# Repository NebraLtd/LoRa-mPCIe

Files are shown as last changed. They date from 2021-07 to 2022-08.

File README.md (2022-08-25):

# LoRa-mPCIe
Open source mPCIe LoRa® concentrators from Nebra

## Branches

This repo contains a number of branches with different versions of the LoRa mPCIe hardware as set out below.

### Main

The [main branch of this repo](https://github.com/NebraLtd/LoRa-mPCIe) contains the initial design of the SX1302/3 concentrator but it is based on the original version of the Semtech reference design. It is therefore outdated and is here just for reference purposes. **This hardware has not been verified with prototypes. We do not recommend you use this design.**

### v1.1

The [v1.1 branch of this repo](https://github.com/NebraLtd/LoRa-mPCIe/tree/v1.1) is the latest version of the SX1302/3 based LoRa concentrator design, based on the v3 Semtech Corecell reference design.

There are multiple variants (USB/SPI versions, GNSS/no-GNSS versions and different frequency options). Visit the [v1.1 VARIANTS file](https://github.com/NebraLtd/LoRa-mPCIe/blob/v1.1/VARIANTS.md) for more information on the different hardware versions and how to produce them.

### v1.2
The development can be followed on the v1.2 branch but keeping the branch unmerged to master would create issues as branches generally accepted as unstable. Also the design will be ended with v1.2 from various reasons (Branding issues with Semtech, semantic versioning does not work in hardware design as in software development)

The variant files also can be observed in the Output's folder under their respective folders.

Note: Successor of this design will appear soon in another repo.

### 470/433

In the future, we will have our 470 MHz and 433 MHz designs available as well. As the design differs considerably from the 868/915 versions it may be in a separate branch.

## Open Source Hardware Certification

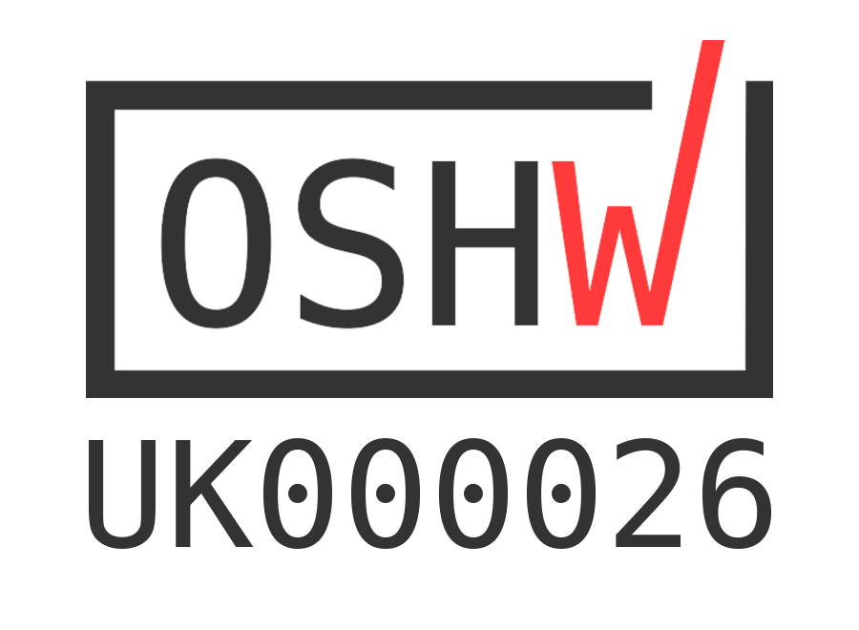
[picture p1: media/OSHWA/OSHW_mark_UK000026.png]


We are proud to announce that the Nebra LoRa mPCIe Concentrator project is certified as Open Source Hardware by the Open Source Hardware Association ([OSHWA](https://www.oshwa.org/)). The registration number for this project is [UK000026](https://certification.oshwa.org/uk000026.html).

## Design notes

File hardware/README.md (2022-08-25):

# LoRa Gateway mini-PCIe Module (SX1302/3) KiCad Open Source Design

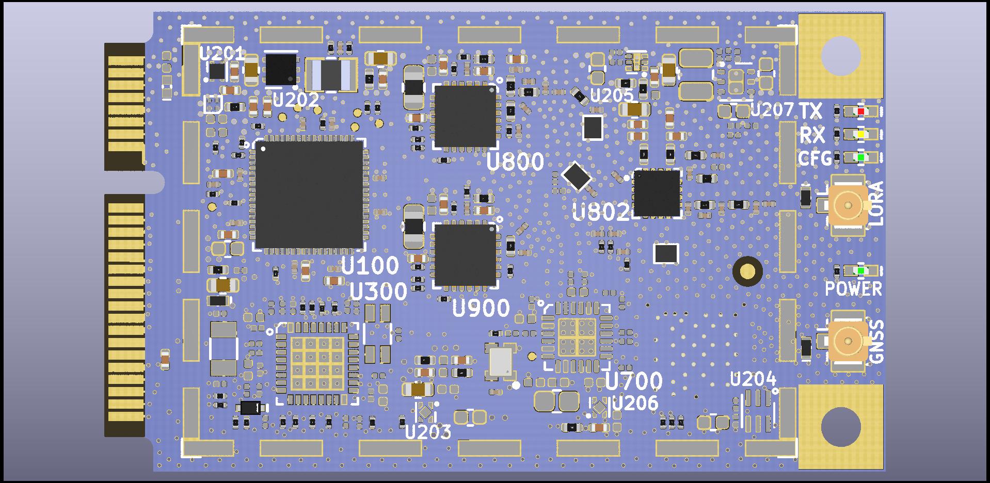
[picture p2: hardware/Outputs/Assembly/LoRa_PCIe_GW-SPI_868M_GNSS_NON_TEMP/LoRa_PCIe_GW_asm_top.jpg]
LoRa_PCIe_GW_asm_top


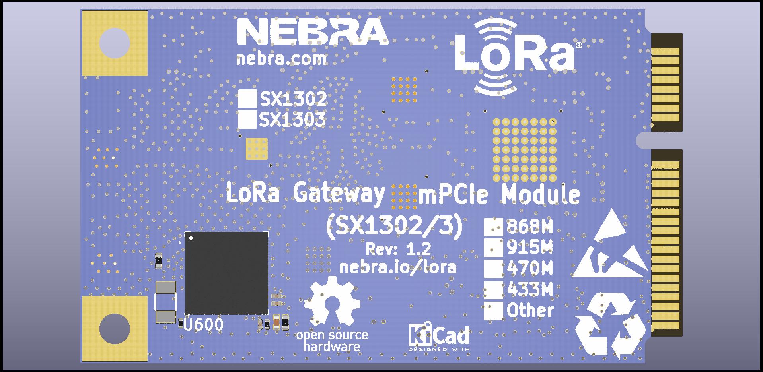
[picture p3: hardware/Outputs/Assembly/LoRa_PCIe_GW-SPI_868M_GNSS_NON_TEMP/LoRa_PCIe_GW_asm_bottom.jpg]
LoRa_PCIe_GW_asm_bottom


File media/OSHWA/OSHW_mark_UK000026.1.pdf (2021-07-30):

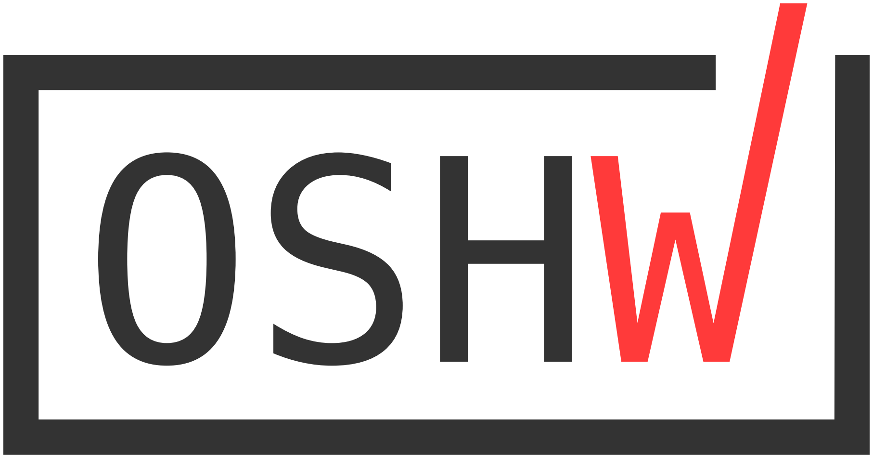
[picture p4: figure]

UK000026

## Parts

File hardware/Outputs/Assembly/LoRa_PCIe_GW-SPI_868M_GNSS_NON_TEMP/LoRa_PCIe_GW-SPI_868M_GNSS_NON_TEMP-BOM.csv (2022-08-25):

Reference | Quantity | Value | Footprint | Datasheet | Description | Manufacturer | Part Number | Price[1k] | Supplier Link | Label | Alternatives | Alternative1
A2 A1 | 2 | U.FL | LoRa_PCIe_GW:U.FL-R-SMT_Hirose |  | U.FL (UMCC) Connector Receptacle, Male Pin 50Ohm Surface Mount Solder | Hirose | U.FL-R-SMT-1(80) | 0.65 | https://www.digikey.com/en/products/detail/hirose-electric-co-ltd/U-FL-R-SMT-1-80/3978495 | GPS
C101 C111 C112 C104 C202 C201 C200 C226 C816 C916 | 10 | 1uF | LoRa_PCIe_GW:ccer_402_smd_small |  | 1µF ±20% 10V Ceramic Capacitor X5R 0402 (1005 Metric) | Murata | GRM153R61A105ME95D | 0.038 | https://www.digikey.com/en/products/detail/murata-electronics/GRM153R61A105ME95D/4904820
C108 C107 C105 C102 C110 C109 C103 C106 C100 C600 C602 C838 | 12 | 100nF | LoRa_PCIe_GW:ccer_201_smd_small |  | 0.1µF ±10% 16V Ceramic Capacitor X7S 0201 (0603 Metric) | Murata | GRM033C71C104KE14D | 0.01 | https://www.digikey.com/en/products/detail/murata-electronics/GRM033C71C104KE14D/5027472
C203 | 1 | 10uF | LoRa_PCIe_GW:ccer_603_smd_small |  | 10µF ±10% 16V Ceramic Capacitor X5R 0603 (1608 Metric) | Murata | GRM188R61C106KAAL | 0.1 | https://www.digikey.com/en/products/detail/murata-electronics/GRM188R61C106KAALJ/4905339
C204 C822 | 2 | 4.7uF | LoRa_PCIe_GW:ccer_603_smd_small |  | 4.7µF ±10% 16V Ceramic Capacitor X5R 0603 (1608 Metric) | Murata | GRM188R61C475KAAJD | 0.089 | https://www.digikey.com/en/products/detail/murata-electronics/GRM188R61C475KAAJD/5027566
C224 | 1 | 4.7uF | LoRa_PCIe_GW:ccer_402_smd_small |  | 4.7µF ±20% 6.3V Ceramic Capacitor X5R 0402 (1005 Metric) | Murata | GRM155R60J475ME47D | 0.089 | https://www.digikey.com/en/products/detail/murata-electronics/GRM155R60J475ME47D/3694656
C231 | 1 | 22pF | LoRa_PCIe_GW:ccer_201_smd_small |  | 22PF ±1% 50V Ceramic Capacitor C0G, NP0 0201 (0603 Metric) | Murata | GRM0335C1H220FA01D | 0.01 | https://www.digikey.com/en/products/detail/murata-electronics/GRM0335C1H220FA01D/11618542
C308 C206 C215 | 3 | 47uF | LoRa_PCIe_GW:ccer_603_smd_small |  | Multilayer ceramic capacitors X5R ±20%, 6.3V | Murata | GRM188R60J476ME15D | 0.1 | https://www.digikey.com/en/products/detail/murata-electronics/GRM188R61C106KAALJ/4905339
C312 C221 C220 C208 C210 C216 C818 C918 | 8 | 100nF | LoRa_PCIe_GW:ccer_402_smd_small |  | Multilayer ceramic capacitors X7R ±10%, 16V | Murata | GMD155R71C104KA11 | 0.01 | https://www.digikey.com/en/products/detail/murata-electronics/GMD155R71C104KA11D/10696609
C601 C802 | 2 | 47pF | LoRa_PCIe_GW:ccer_201_smd_small |  | 47pF ±5% 50V Ceramic Capacitor C0G, NP0 0201 (0603 Metric) | Murata | GRM0335C1H470JA01D | 0.0036 | https://www.digikey.com/en/products/detail/murata-electronics/GRM0335C1H470JA01D/2542245
C801 | 1 | 47nF | LoRa_PCIe_GW:ccer_402_smd_small |  | 0.047µF ±10% 16V Ceramic Capacitor X7R 0402 (1005 Metric) | Murata | GRM155R71C473KA01J | 0.012 | https://www.digikey.com/en/products/detail/murata-electronics/GRM155R71C473KA01J/2610901
C804 C832 C831 | 3 | 3.3pF | LoRa_PCIe_GW:ccer_201_smd_small |  | 3.3pF ±0.05pF 50V Ceramic Capacitor C0G, NP0 0201 (0603 Metric) | Murata | GJM0335C1H3R3WB01D | 0.026 | https://www.digikey.com/en/products/detail/murata-electronics/GJM0335C1H3R3WB01D/13401747
C805 | 1 | 5.6pF | LoRa_PCIe_GW:ccer_201_smd_small |  | 5.6pF ±0.05pF 50V Ceramic Capacitor C0G, NP0 0201 (0603 Metric) | Murata | GRM0335C1H5R6WA01D | 0.005 | https://www.digikey.com/en/products/detail/murata-electronics/GRM0335C1H5R6WA01D/11618868
C806 | 1 | 39pF | LoRa_PCIe_GW:ccer_201_smd_small |  | 39pF ±1% 50V Ceramic Capacitor C0G, NP0 0201 (0603 Metric) | Murata | GRM0335C1H390FA01D | 0.0057 | https://www.digikey.com/en/products/detail/murata-electronics/GRM0335C1H390FA01D/11618461
C807 | 1 | 2.2pF | LoRa_PCIe_GW:ccer_201_smd_small |  | 2.2pF ±0.05pF 50V Ceramic Capacitor C0G, NP0 0201 (0603 Metric) | Murata | GJM0335C1H2R2WB01D | 0.026 | https://www.digikey.com/en/products/detail/murata-electronics/GJM0335C1H2R2WB01D/11618467
C808 C908 C828 | 3 | 10pF | LoRa_PCIe_GW:ccer_201_smd_small |  | 10pF ±1% 50V Ceramic Capacitor C0G, NP0 0201 (0603 Metric) | Murata | GRM0335C1H100FA01 | 0.005 | https://www.digikey.com/en/products/detail/murata-electronics/GRM0335C1H100FA01J/4358681
C811 C812 C911 C912 | 4 | 3.6pF | LoRa_PCIe_GW:ccer_201_smd_small |  | 3.6pF ±0.05pF 25V Ceramic Capacitor C0G, NP0 0201 (0603 Metric) | Murata | GJM0335C1E3R6WB01J | 0.022 | https://www.digikey.com/en/products/detail/murata-electronics/gjm0335c1e3r6wb01j/2592609
C817 C917 | 2 | 470nF | LoRa_PCIe_GW:ccer_402_smd_small |  | 0.47µF ±10% 10V Ceramic Capacitor X5R 0402 (1005 Metric) | Murata | GRM155R61A474KE15D | 0.024 | https://www.digikey.com/en/products/detail/murata-electronics/GRM155R61A474KE15D/702528
C823 | 1 | 10nF | LoRa_PCIe_GW:ccer_402_smd_small |  | 10000pF ±10% 10V Ceramic Capacitor X5R 0402 (1005 Metric) | Murata | GRM155R61A103KA01D | 0.007 | https://www.digikey.com/en/products/detail/murata-electronics/GRM155R61A103KA01D/2610840
C824 | 1 | 1nF | LoRa_PCIe_GW:ccer_402_smd_small |  | 1000pF ±10% 16V Ceramic Capacitor X7R 0402 (1005 Metric) | Murata | GRM155R71C102KA01D | 0.007 | https://www.digikey.com/en/products/detail/murata-electronics/GRM155R71C102KA01D/2610889
C826 C825 | 2 | 100pF | LoRa_PCIe_GW:ccer_402_smd_small |  | 100pF ±1% 50V Ceramic Capacitor C0G, NP0 0402 (1005 Metric) | Murata | GRM1555C1H101FA01D | 0.016 | https://www.digikey.com/en/products/detail/murata-electronics/GRM1555C1H101FA01D/3693919
C829 | 1 | 1.3pF | LoRa_PCIe_GW:ccer_201_smd_small |  | 1.3pF ±0.05pF 50V Ceramic Capacitor C0G, NP0 0201 (0603 Metric) | Murata | GJM0335C1H1R3WB01 | 0.02 | https://www.digikey.com/en/products/detail/murata-electronics/GJM0335C1H1R3WB01D/11618853
C830 | 1 | 1.5pF | LoRa_PCIe_GW:ccer_201_smd_small |  | 1.5pF ±0.05pF 50V Ceramic Capacitor C0G, NP0 0201 (0603 Metric) | Murata | GJM0335C1H1R5WB01 | 0.026 | https://www.digikey.com/en/products/detail/murata-electronics/GJM0335C1H1R5WB01D/11618773
C833 | 1 | 2.7pF | LoRa_PCIe_GW:ccer_201_smd_small |  | 2.7 pF ±0.1pF 50V Ceramic Capacitor C0G, NP0 0201 (0603 Metric) | Murata | GJM0335C1H2R7BB01D | 0.008 | https://www.digikey.com/en/products/detail/murata-electronics/GJM0335C1H2R7BB01D/9758987
C834 C819 C815 C820 C821 C809 | 6 | 56pF | LoRa_PCIe_GW:ccer_201_smd_small |  | 56pF ±1% 50V Ceramic Capacitor C0G, NP0 0201 (0603 Metric) | Murata | GRM0335C1H560FA01D | 0.0057 | https://www.digikey.com/en/products/detail/murata-electronics/GRM0335C1H560FA01D/11618638
D101 | 1 | BAT54 | LoRa_PCIe_GW:SOD523 |  | Schottky 200mA (DC) Surface Mount SOD-523 | ON Semiconductor | BAT54XV2T1G | 0.046 | https://www.digikey.com/en/products/detail/on-semiconductor/BAT54XV2T1G/918321
D302 | 1 | 20V | LoRa_PCIe_GW:SLP1006P2T |  | 20V Clamp 4A (8/20µs) Ipp Tvs Diode Surface Mount SLP1006P2T | Semtech | RCLAMP0531T.TCT | 0.39 | https://www.digikey.com/en/products/detail/semtech-corporation/RCLAMP0531T-TCT/2236834
D600 D801 | 2 | ~ | LoRa_PCIe_GW:SLP1006P2T |  | TVS DIODE 4V 1005 | Murata | LXES15AAA1-153 | 0.046 | https://www.digikey.com/en/products/detail/murata-electronics/LXES15AAA1-153/5843762
FB302 FB208 FB207 FB212 FB203 FB211 FB801 | 7 | Ferrite beads | LoRa_PCIe_GW:rlc_402_smd_small |  | 10 Ohms @ 100MHz 1 Power Line Ferrite Bead 0402 (1005 Metric) 1A 25mOhm | Murata | BLM15PG100SN1D | 0.027 | https://www.digikey.com/en/products/detail/murata-electronics/BLM15PG100SN1D/2587980
L200 | 1 | 2.2uH | LoRa_PCIe_GW:LQM2HPN2R2MJ0L |  | 2.2µH Shielded Multilayer Inductor 1A 150mOhm Max 1008 (2520 Metric) | Murata | LQM2HPN2R2MJ0L | 0.14 | https://www.digikey.com/en/products/detail/murata-electronics/LQM2HPN2R2MJ0L/2594611
L601 L801 | 2 | 47nH | LoRa_PCIe_GW:rlc_402_smd_small |  | 47nH Unshielded Wirewound Inductor 210mA 1.08Ohm Max 0402 (1005 Metric) | Murata | LQW15AN47NJ00D | 0.063 | https://www.digikey.com/en/products/detail/murata-electronics/LQW15AN47NJ00D/584363
L803 | 1 | 2.5nH | LoRa_PCIe_GW:rlc_402_smd_small |  | 2.5nH Unshielded Wirewound Inductor 850mA 50mOhm Max 0402 (1005 Metric) | Murata | LQW15AN2N5C00D | 0.066 | https://www.digikey.com/en/products/detail/murata-electronics/LQW15AN2N5C00D/2594887
L804 | 1 | 4.7nH | LoRa_PCIe_GW:rlc_402_smd_small |  | 4.7nH Unshielded Wirewound Inductor 750mA 70mOhm Max 0402 (1005 Metric) | Murata | LQW15AN4N7C00D | 0.066 | https://www.digikey.com/en/products/detail/murata-electronics/LQW15AN4N7C00D/584348
L806 L906 | 2 | 12nH | LoRa_PCIe_GW:rlc_402_smd_small |  | 12nH Unshielded Wirewound Inductor 500mA 140mOhm Max 0402 (1005 Metric) | Murata | LQW15AN12NH00D | 0.066 | https://www.digikey.com/en/products/detail/murata-electronics/LQW15AN12NH00D/2594852
L807 L907 | 2 | 15uH | LoRa_PCIe_GW:rlc_805_smd_small |  | 15µH Shielded Multilayer Inductor 250mA 950mOhm 0805 (2012 Metric) | TDK | MLZ2012M150WTD25 | 0.068 | https://www.digikey.com/en/products/detail/tdk-corporation/MLZ2012M150WTD25/4743191
L809 | 1 | 6.8nH | LoRa_PCIe_GW:rlc_402_smd_small |  | 6.8nH Unshielded Wirewound Inductor 1.45A 68mOhm Max 0402 (1005 Metric) | Murata | LQW15AN6N8G80D | 0.1 | https://www.digikey.com/en/products/detail/murata-electronics/LQW15AN6N8G80D/4905972
L810 | 1 | 3.0nH | LoRa_PCIe_GW:rlc_402_smd_small |  | 3nH Unshielded Wirewound Inductor 1.35A 63mOhm Max 0402 (1005 Metric) | Murata | LQW15AN3N0C80D | 0.09 | https://www.digikey.com/en/products/detail/murata-electronics/LQW15AN3N0C80D/4905927
L811 | 1 | 7.5nH | LoRa_PCIe_GW:rlc_402_smd_small |  | 7.5nH Unshielded Wirewound Inductor 570mA 130mOhm Max 0402 (1005 Metric) | Murata | LQW15AN7N5J00D | 0.063 | https://www.digikey.com/en/products/detail/murata-electronics/LQW15AN7N5J00D/584352
L812 | 1 | 1.2nH | LoRa_PCIe_GW:rlc_402_smd_small |  | 1.2nH Unshielded Thick Film Inductor 390mA 100mOhm Max 0402 (1005 Metric) | Murata | LQP15MN1N2B02 | 0.07 | https://www.digikey.com/en/products/detail/murata-electronics/LQP15MN1N2B02D/584334
L813 L814 | 2 | 5.6nH | LoRa_PCIe_GW:rlc_402_smd_small |  | 5.6nH Unshielded Wirewound Inductor 800mA 51mOhm Max 0402 (1005 Metric) | Murata | LQW15AN5N6D10D | 0.072 | https://www.digikey.com/en/products/detail/murata-electronics/LQW15AN5N6D10D/2594939
LED1 | 1 | RED | LoRa_PCIe_GW:CD1005-0402-RED |  | Red 630nm LED Indication - Discrete 1.95V 0402 (1005 Metric) | Kingbright | APHHS1005SURCK | 0.12 | https://www.digikey.com/en/products/detail/kingbright/APHHS1005SURCK/1747502 | TX_ON
LED2 LED4 | 2 | GREEN | LoRa_PCIe_GW:CD1005-0402 |  | Green 570nm LED Indication - Discrete 1.9V 0402 (1005 Metric) | Kingbright | APHHS1005LCGCK | 0.11 | https://www.digikey.com/en/products/detail/kingbright/APHHS1005LCGCK/7318974 | CONFIG_OK
LED3 | 1 | YELLOW | LoRa_PCIe_GW:CD1005-0402-YELLOW |  | Yellow 590nm LED Indication - Discrete 1.85V 0402 (1005 Metric) | Kingbright | APHHS1005LSYCK/J3-PF | 0.16 | https://www.digikey.com/en/products/detail/kingbright/APHHS1005LSYCK-J3-PF/7318978 | RX_ON
R102 R301 R308 R309 R302 R317 R316 R318 R319 R332 R334 R331 R333 R326 | 14 | 100R | LoRa_PCIe_GW:rlc_201_smd_small |  | 100 Ohms ±1% 0.05W, 1/20W Chip Resistor 0201 (0603 Metric) Thick Film | Vishay Dale | CRCW0201100R | 0.037 | https://www.digikey.com/en/products/detail/vishay-dale/CRCW0201100RFKED/1967973
R103 R101 R107 R201 | 4 | 47k | LoRa_PCIe_GW:rlc_201_smd_small |  | 47 kOhms ±5% 0.05W, 1/20W Chip Resistor 0201 Thick Film | Vishay Dale | CRCW020147K0 | 0.039 | https://www.digikey.com/en/products/detail/vishay-dale/CRCW020147K0FKED/1968131
R104 R105 | 2 | 680R | LoRa_PCIe_GW:rlc_201_smd_small |  | 680 Ohms ±1% 0.05W, 1/20W Chip Resistor 0201 (0603 Metric) Thick Film | Vishay Dale | CRCW0201680R | 0.011 | https://www.digikey.com/en/products/detail/vishay-dale/CRCW0201680RFNED/1199791
R106 | 1 | 820R | LoRa_PCIe_GW:rlc_201_smd_small |  | 820 Ohms ±5% 0.05W, 1/20W Chip Resistor 0201 (0603 Metric) Thick Film | Vishay Dale | CRCW0201820R | 0.012 | https://www.digikey.com/en/products/detail/vishay-dale/CRCW0201820RJNED/1178449
R108 R600 | 2 | 10R | LoRa_PCIe_GW:rlc_201_smd_small |  | 10 Ohms ±5% 0.05W, 1/20W Chip Resistor 0201 Thick Film | Vishay Dale | CRCW020110R0JNED | 0.0052 | https://www.digikey.com/en/products/detail/vishay-dale/CRCW020147K0FKED/1968131
R113 R122 R114 R124 R110 R115 R112 R123 R121 R120 R109 R125 R111 R602 R200 R815 | 16 | 0R | LoRa_PCIe_GW:rlc_201_smd_small |  | 0 Ohms Jumper 0.05W, 1/20W Chip Resistor 0201 (0603 Metric) Thick Film | Vishay Dale | CRCW02010000Z0ED | 0.006 | https://www.digikey.com/en/products/detail/vishay-dale/CRCW02010000Z0ED/1178434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
R116 R117 R601 R206 R203 | 5 | 4.7k | LoRa_PCIe_GW:rlc_201_smd_small |  | 4.7 kOhms ±1% 0.05W, 1/20W Chip Resistor 0201 (0603 Metric) Thick Film | Vishay Dale | CRCW02014K70FNED | 0.011 | https://www.digikey.com/en/products/detail/vishay-dale/CRCW02014K70FNED/1199881
R221 R222 R813 R913 | 4 | 0R | LoRa_PCIe_GW:rlc_402_smd_small |  | CRCW04020000ZSTD | Vishay Dale | CRCW04020000ZSTD | 0.014 | https://www.digikey.com/en/products/detail/vishay-dale/CRCW04020000ZSTD/1226552
R231 R232 | 2 | 182K | LoRa_PCIe_GW:rlc_201_smd_small |  | 182K OHM 1% 1/20W, Thick Film | Vishay Dale | CRCW0201182KFKED | 0.039 | https://www.digikey.com/en/products/detail/vishay-dale/CRCW0201182KFKED/1968150
R330 R208 R805 R809 R807 | 5 | 1k | LoRa_PCIe_GW:rlc_201_smd_small |  | 1k Ohm ±5% 0.05W, 1/20W Chip Resistor 0201 (0603 Metric) - Thick Film | Vishay Dale | CRCW02011K00JNED | 0.073 | https://www.digikey.com/en/products/detail/vishay-dale/CRCW02011K00JNED/1178450
R801 R901 | 2 | 220R | LoRa_PCIe_GW:rlc_201_smd_small |  | 220 Ohms ±5% 0.05W, 1/20W Chip Resistor 0201 (0603 Metric) Thick Film | Vishay Dale | CRCW0201220RJNED | 0.007 | https://www.digikey.com/en/products/detail/vishay-dale/CRCW0201220RJNED/1178444
RF1 | 1 | Shield Frame | LoRa_PCIe_GW:SMS-458F_Shield | https://leadertechinc.com/wp-content/uploads/2016/03/SMS-458-REV-A.pdf | RF Shield Frame 1.070 (27.18mm) X 1.540" (39.12mm) Surface Mount" | Leader Tech | SMS-458F | 1.82 | https://www.digikey.com/en/products/detail/leader-tech-inc/SMS-458F/7203557
RF2 | 1 | Shield Cover | LoRa_PCIe_GW:SMS-458C_Shield_cover | https://leadertechinc.com/wp-content/uploads/2016/03/SMS-458-REV-A.pdf | RF Shield Cover 1.094 (27.79mm) X 1.564" (39.73mm) Non-Vented Surface Mount" | Leader Tech | SMS-458C | 0.32 | https://www.digikey.com/en/products/detail/leader-tech-inc/SMS-458C/7203485
U100 | 1 | SX1303 | LoRa_PCIe_GW:vqfn68_7x7mm | https://semtech.my.salesforce.com/sfc/p/ | Digital Baseband Chip for LoRaWAN network gateways | Semtech Corporation | SX1303IMLTRT | 20 | https://www.digikey.com/en/products/detail/semtech-corporation/SX1303IMLTRT/13419419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
U201 | 1 | 3V3 | LoRa_PCIe_GW:UDFN4_1x1mm |  | Linear Voltage Regulator IC Positive Fixed 1 Output 300mA 4-UDFN (1.0x1.0) | ON Semiconductor | NCP114AMX330TCG | 0.079 | https://www.digikey.com/en/products/detail/on-semiconductor/NCP114AMX330TBG/6166731 |  | NCP4586DMU33TCG
U202 | 1 | TPS62260DRV | LoRa_PCIe_GW:DRV0006A_V |  | Buck Switching Regulator IC Positive Adjustable 0.6V 1 Output 600mA | Texas Instruments | TPS62260DRV | 0.85 | https://www.digikey.com/en/products/detail/texas-instruments/TPS62260DRVR/1908045 |  |  | SY20183LDEC
U600 | 1 | EVA-M8M-0 | LoRa_PCIe_GW:LGA43R65P9X9_700X700X116 | https://www.u-blox.com/en/docs/UBX-16014189 | GNSS RF Receiver Galileo, GLONASS, GPS 1.575GHz -167dBm | U-Blox | EVA-M8M-0 | 15.6 | https://www.digikey.com/en/products/detail/u-blox/EVA-M8M-0/6150634
U800 U900 | 2 | SX1250 | LoRa_PCIe_GW:vqfn24_4x4mm | https://semtech.my.salesforce.com/sfc/p/ | RF TxRx Only LoRaWAN 150MHz ~ 960MHz | Semtech | SX1250IMLTRT | 2.9 | https://www.digikey.com/en/products/detail/semtech-corporation/SX1250IMLTRT/10379521
U802 | 1 | SKY66423-11 | LoRa_PCIe_GW:SKY66420_16P_3x3mm | https://www.skyworksinc.com/-/media/SkyWorks/Documents/Products/2801-2900/SKY66423_11_204566J.pdf | RF Front End 860MHz ~ 930MHz General Purpose 16-MCM (3x3) | Skyworks | SKY66423-11 | 1.4 | https://www.digikey.com/en/products/detail/skyworks-solutions-inc/SKY66423-11/9603432
U803 U801 U805 | 3 | SAW Filter | LoRa_PCIe_GW:QCS5P_1.4x1.1mm |  | 866.5MHz Frequency Remote Control RF SAW Filter (Sound Acoustic Wave) 2.3dB 7MHz Bandwidth 5-SMD, No Lead | Qualcomm & TDK | B39871B4377P810 | 0.92 | https://www.digikey.com/en/products/detail/qualcomm-rf360-a-qualcomm-tdk-joint-venture/B39871B4377P810/9562395
Y800 | 1 | TCXO | LoRa_PCIe_GW:TCXO_2x1_6mm |  | 32MHz TCXO Oscillator 1.8V 4-SMD, No Lead | NDK | NT2016SA 32MHz END4263A | 1 | https://www.digikey.com/en/products/detail/ndk-america-inc/NT2016SA-32M-END4263A/8275433

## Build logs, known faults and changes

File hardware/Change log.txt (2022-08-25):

Rev 1.0_2021_03_11
	- New KiCad project, layout preserved.
	- Added GNSS EVA-M8M.
	- Added 10uF on pin 41 PCIe pin
	- Removed UART signals from PCIe conn to SX1302/3
	- Removed R811 saw filter jumper, not necessary.
	- Replaced Rf Shield with SMS-458.

Rev 1.1_2021_04_13
	- Changed control SX1302 GPIO signals for LEDs according to Corecell_V3
	- Added  Common Mode Choke to USB lines
	- Updated mcu control signals according to Corecell_V3
	- Interface part updated with 5V input power option from PCIe pin2.
	- Update power supply schematic according to Corecell_V3
	- Removed Rf part R802, R803, R804 according to Corecell_V3
	- Changed resitor values R805, R807, R809 to 1k according to Corecell_V3
	- Silkscreen updated.

Rev 1.2_2022_01_18
	- Changed U202 1V2 DCDC from fixed to adjuctable output variant (better sourcing) with additional resistors R231,R232 and capacitor C231
	- Changed U201,U203,U203 LDO (obsolite) to NCP114AMX330TBG
	- Added new assembly variant for non GNSS non Temperature sensor
	- Changed C206,C215 capacitor values from 4.7uF to 47uF
	- Added 100nF capacitors C210 and C216.
	- U203, C212,C213 and FB205 removed from default population, FB203 set instead for direct 3V3 VDD_RF feed.
	- U205, C207, R207 removed from default population, R222 set instead.
	- Improved layout and routing.	
	- GNSS power changed to direct feed from VCC3V3_IN instead of LDO U206.U206,C225 removed from default population, R221 set to default population.
	- Remove R601 for NON_GNSS variants
	- Temp sensor removed from default population. U204, R205, C222, C223 removed from default population and R203,R206 for NON_GNSS variant.
	- New assembly fabrication files for USB GNSS NON TEMP variant.

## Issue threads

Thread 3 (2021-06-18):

Regarding Hardware Change if use IN865

mightChamp, 2021-06-18:
Hello,

Thanks for this great work.
We are following your work, We Have some doubt regarding hardware:
Is this PCB Support IN865 Frequency, or I have to made some changes regarding PCB design or component?

Thank You

mmilann, 2021-06-18:
PCB is to be same, Rf filter passive component values could be optimised for 865MHz, but this is close to 868MHz, so probably this BOM may be fine, especially if you do not use it at maximum power.

mightChamp, 2021-06-19:
Hello,
Thanks for response. I will use it at its maximum power.
Could you please help me regarding IN865 RF Filter Component values?

Thank You

shawaj, 2021-07-29:
@mightChamp you can just use the 868mhz version. We only use two versions - 868 (for EU868, RU864, IN865) and 915 (for US915, AS923-1/2/3/4, AU915, KR920).

The change is just in the configuration file for the module.

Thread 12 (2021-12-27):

Parts to remove for no temp sensor

shawaj, 2021-12-27:
R203, R206, C222, C223, U204, R205

shawaj, 2022-01-22:
Fixed in v1.2 branch

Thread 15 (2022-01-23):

v1.1 and v1.2

shawaj, 2022-01-23:
See two versions below (either is fine for production - depending on chip availability for the U202 part:

## v1.1

This uses the TPS62242DRV in U202.

You will see there are 4 types of BOM:
868 SPI non GPS (for use with ROCK Pi HAT)
868 SPI with GPS (for general sale, small qty batches circa 1k a time)
915 SPI non GPS (for use with ROCK Pi HAT)
915 SPI with GPS (for general sale, small qty batches circa 1k a time)

Further to this, we can also remove R203, R206, C222, C223, U204, R205 from all of these BOMs. They relate to a temperature sensor that we don't need/want to use.

## v1.2

This uses the TPS62260DRV in U202 along with some additional components.

You will see there are 6 types of BOM:
868 SPI non GPS (for use with ROCK Pi HAT)
868 SPI with GPS (for general sale, small qty batches circa 1k a time)
915 SPI non GPS (for use with ROCK Pi HAT)
915 SPI with GPS (for general sale, small qty batches circa 1k a time)
868 USB with GPS (for use with 5G gateway)
915 USB with GPS (for use with 5G gateway)

shawaj, 2022-02-28:
[LoRa-mPCIe-1.2 (2).zip](https://github.com/NebraLtd/LoRa-mPCIe/files/8150449/LoRa-mPCIe-1.2.2.zip)

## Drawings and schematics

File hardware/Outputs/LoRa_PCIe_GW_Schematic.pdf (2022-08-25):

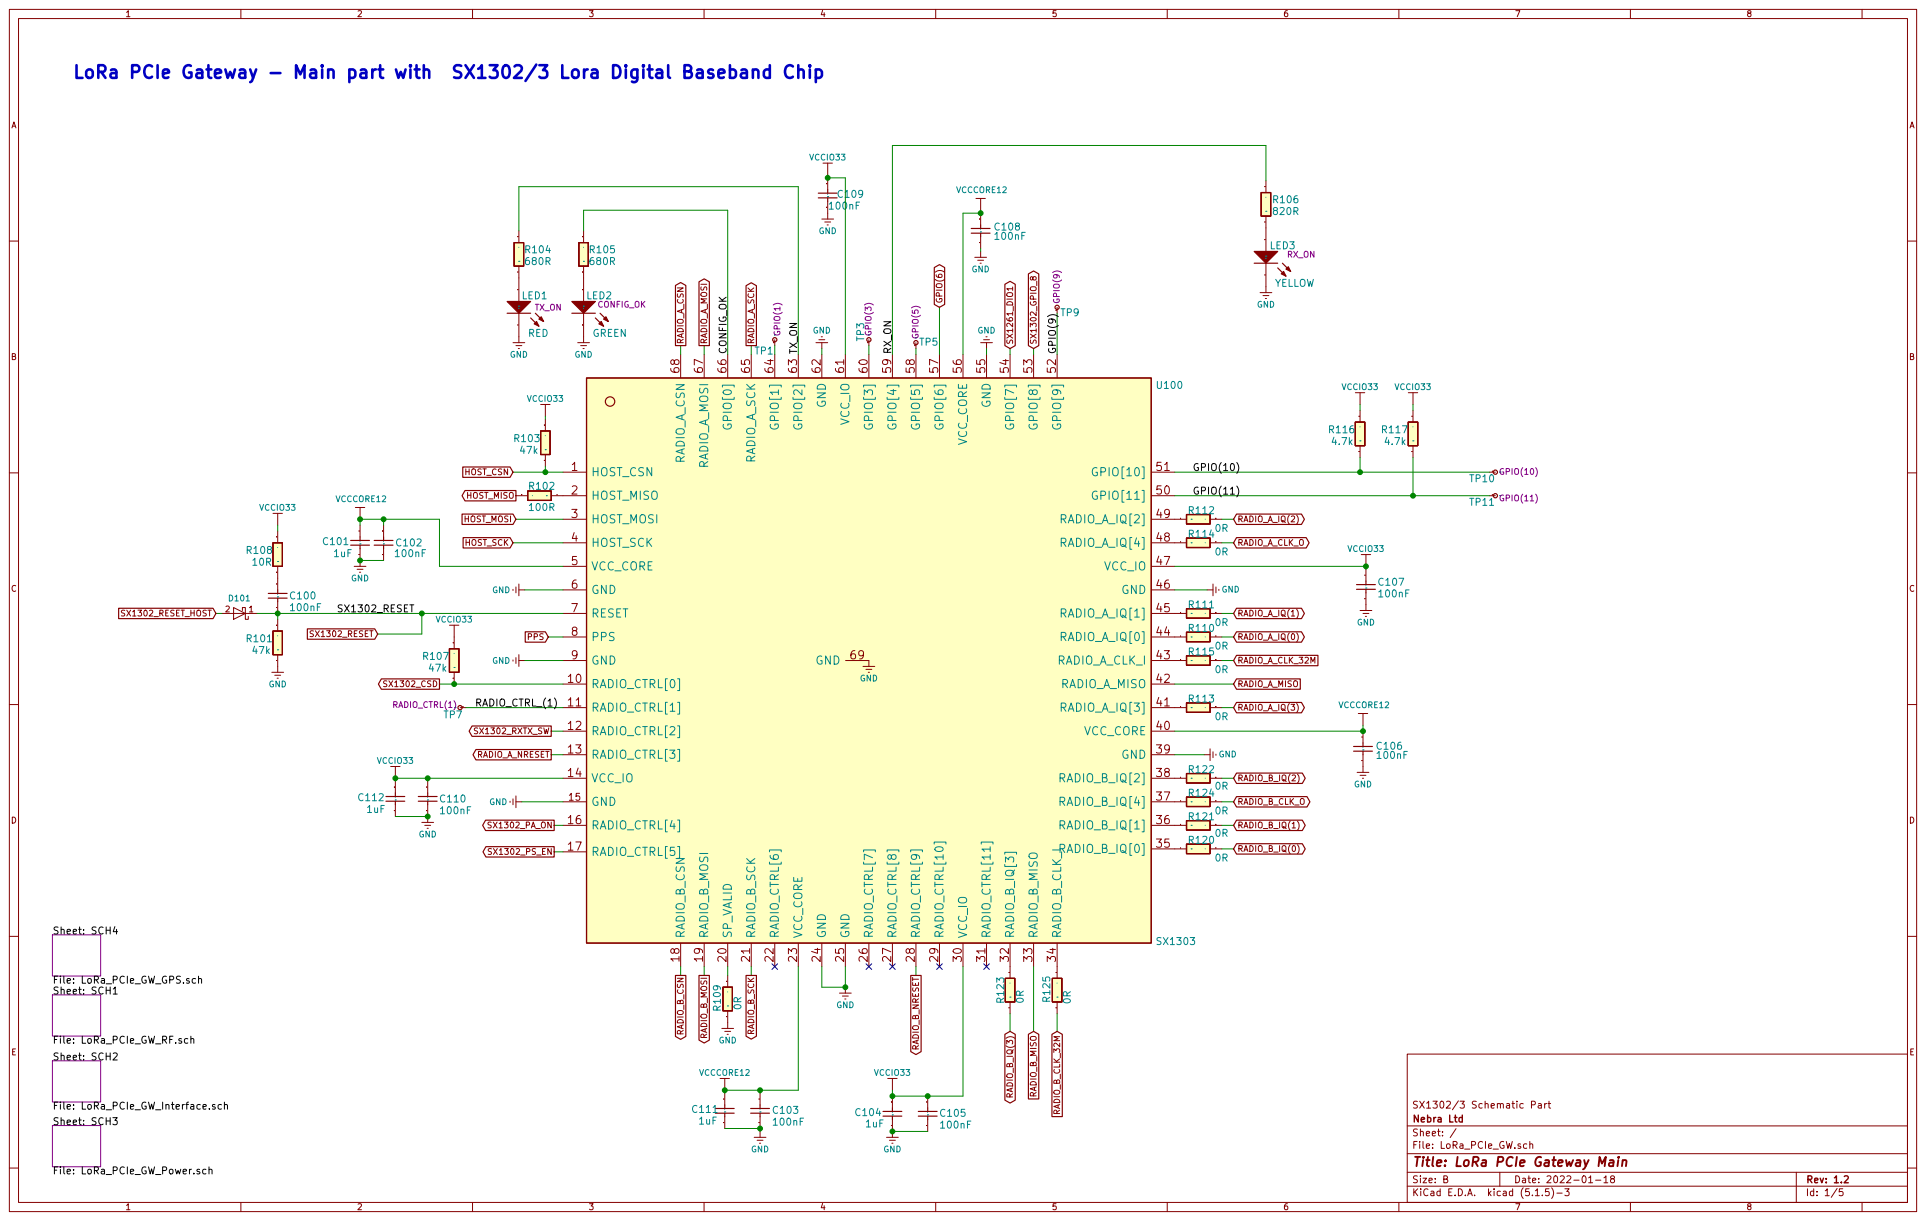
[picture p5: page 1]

File: LoRa_PCIe_GW.sch Sheet: / Nebra Ltd SX1302/3 Schematic Part Sheet: SCH1

Id: 1/5 Title: LoRa PCIe Gateway Main

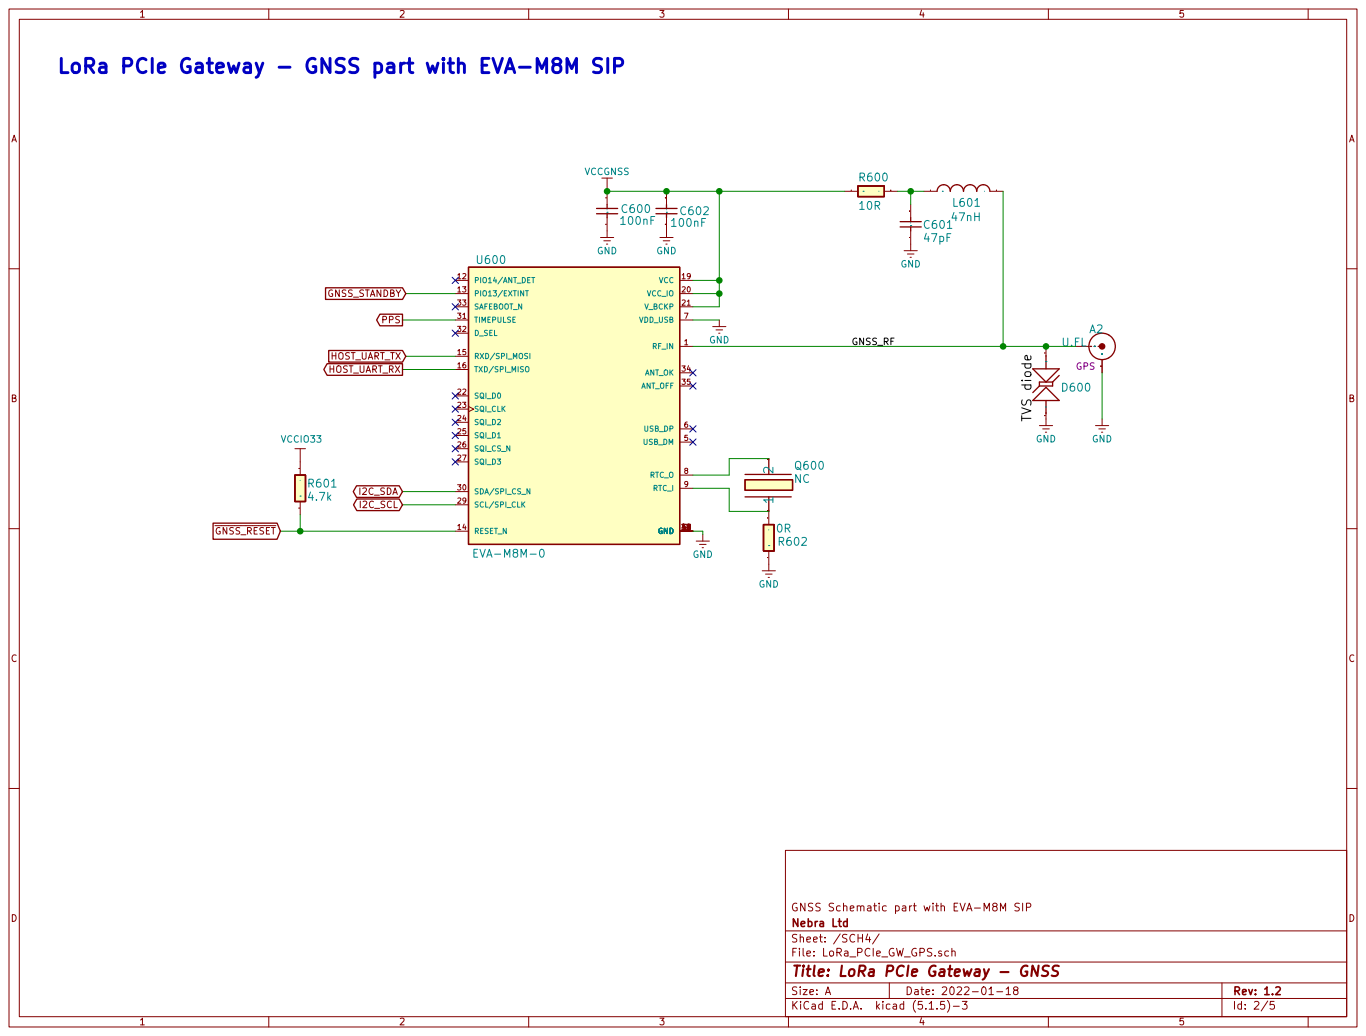
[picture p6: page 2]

GNSS_RF LoRa PCIe Gateway - GNSS part with EVA-M8M SIP

File: LoRa_PCIe_GW_GPS.sch Sheet: /SCH4/ Nebra Ltd GNSS Schematic part with EVA-M8M SIP

Id: 2/5 Title: LoRa PCIe Gateway - GNSS

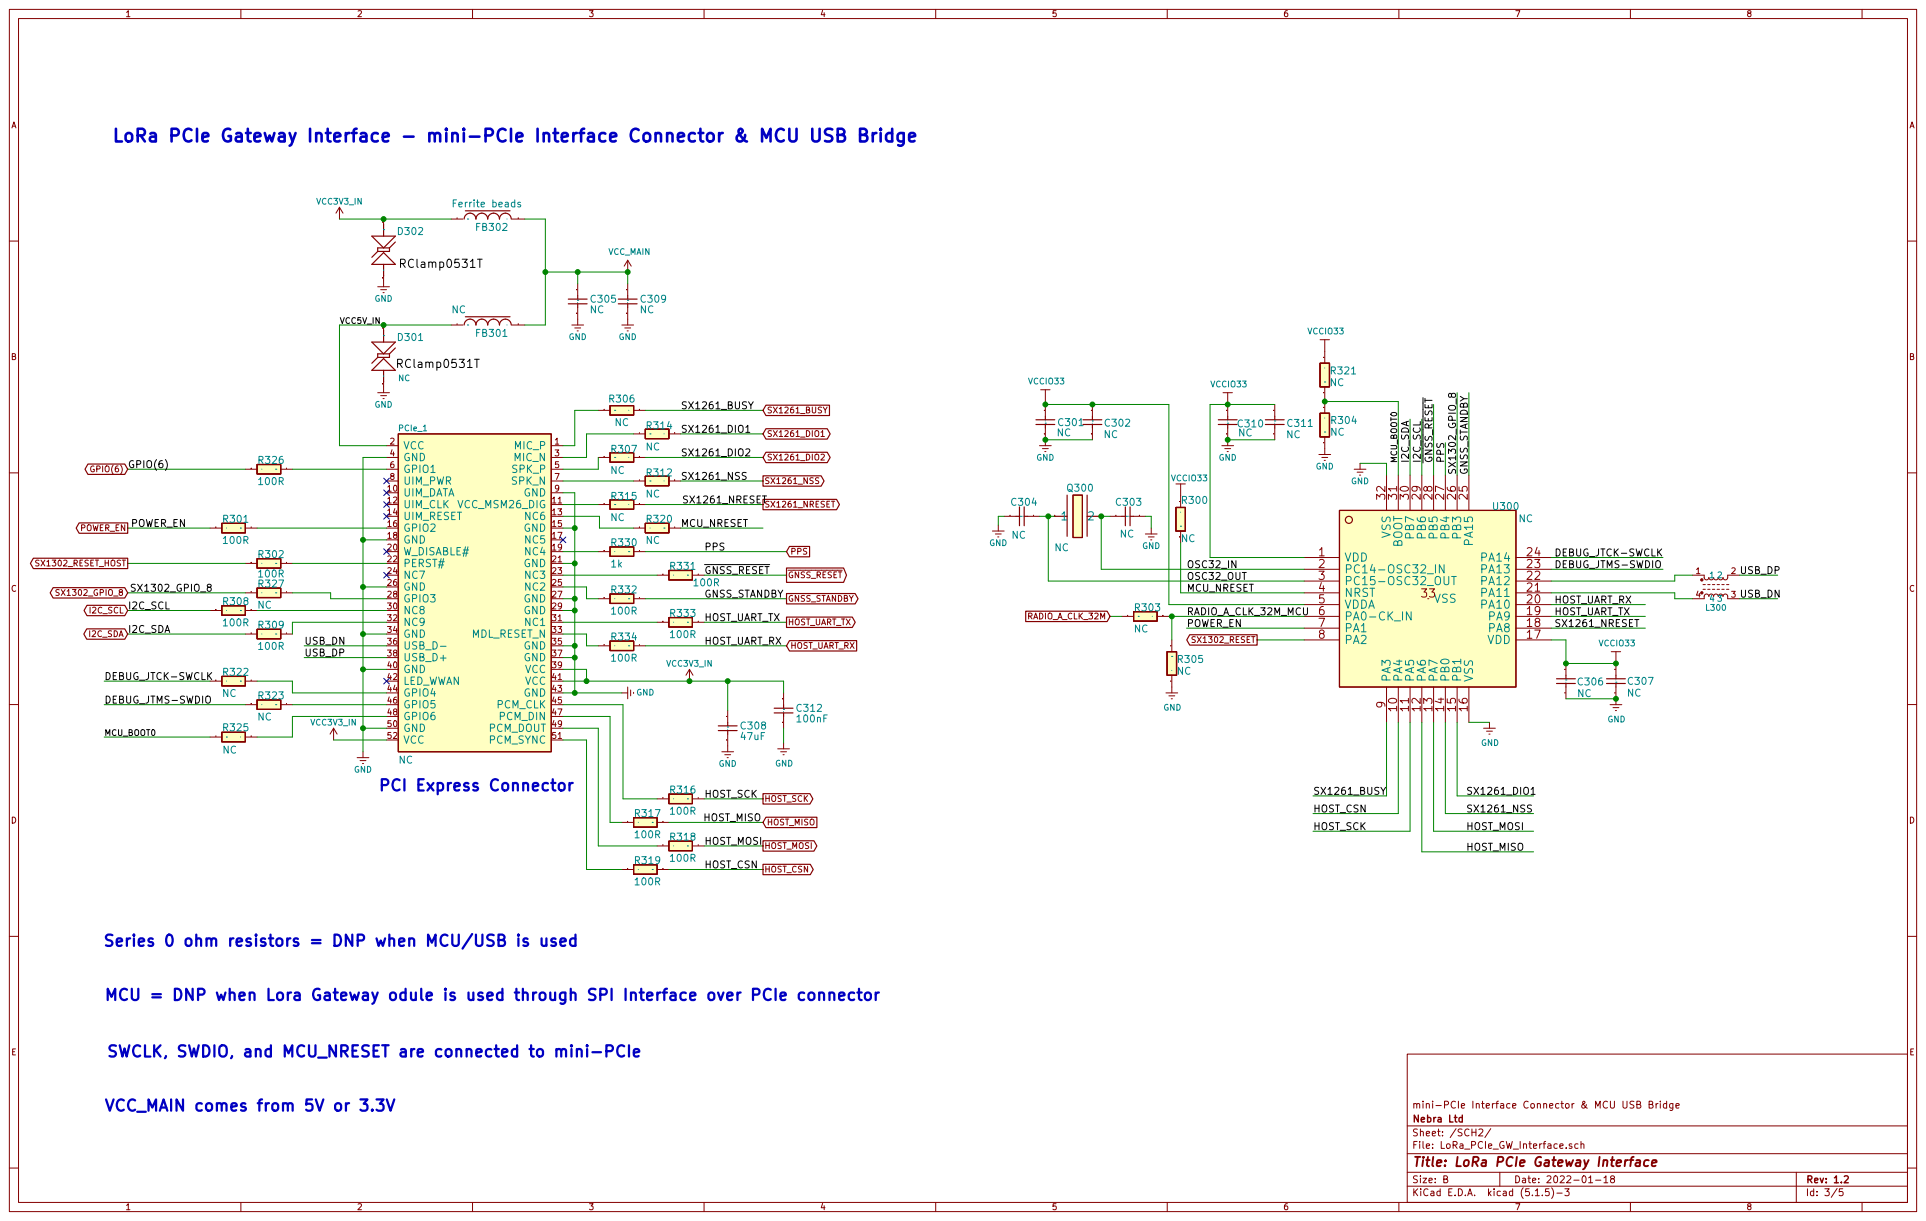
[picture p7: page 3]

LoRa PCIe Gateway Interface - mini-PCIe Interface Connector & MCU USB Bridge

Series 0 ohm resistors = DNP when MCU/USB is used

MCU = DNP when Lora Gateway odule is used through SPI Interface over PCIe connector

SWCLK, SWDIO, and MCU_NRESET are connected to mini-PCIe

File: LoRa_PCIe_GW_Interface.sch Sheet: /SCH2/ Nebra Ltd mini-PCIe Interface Connector & MCU USB Bridge

Id: 3/5 Title: LoRa PCIe Gateway Interface

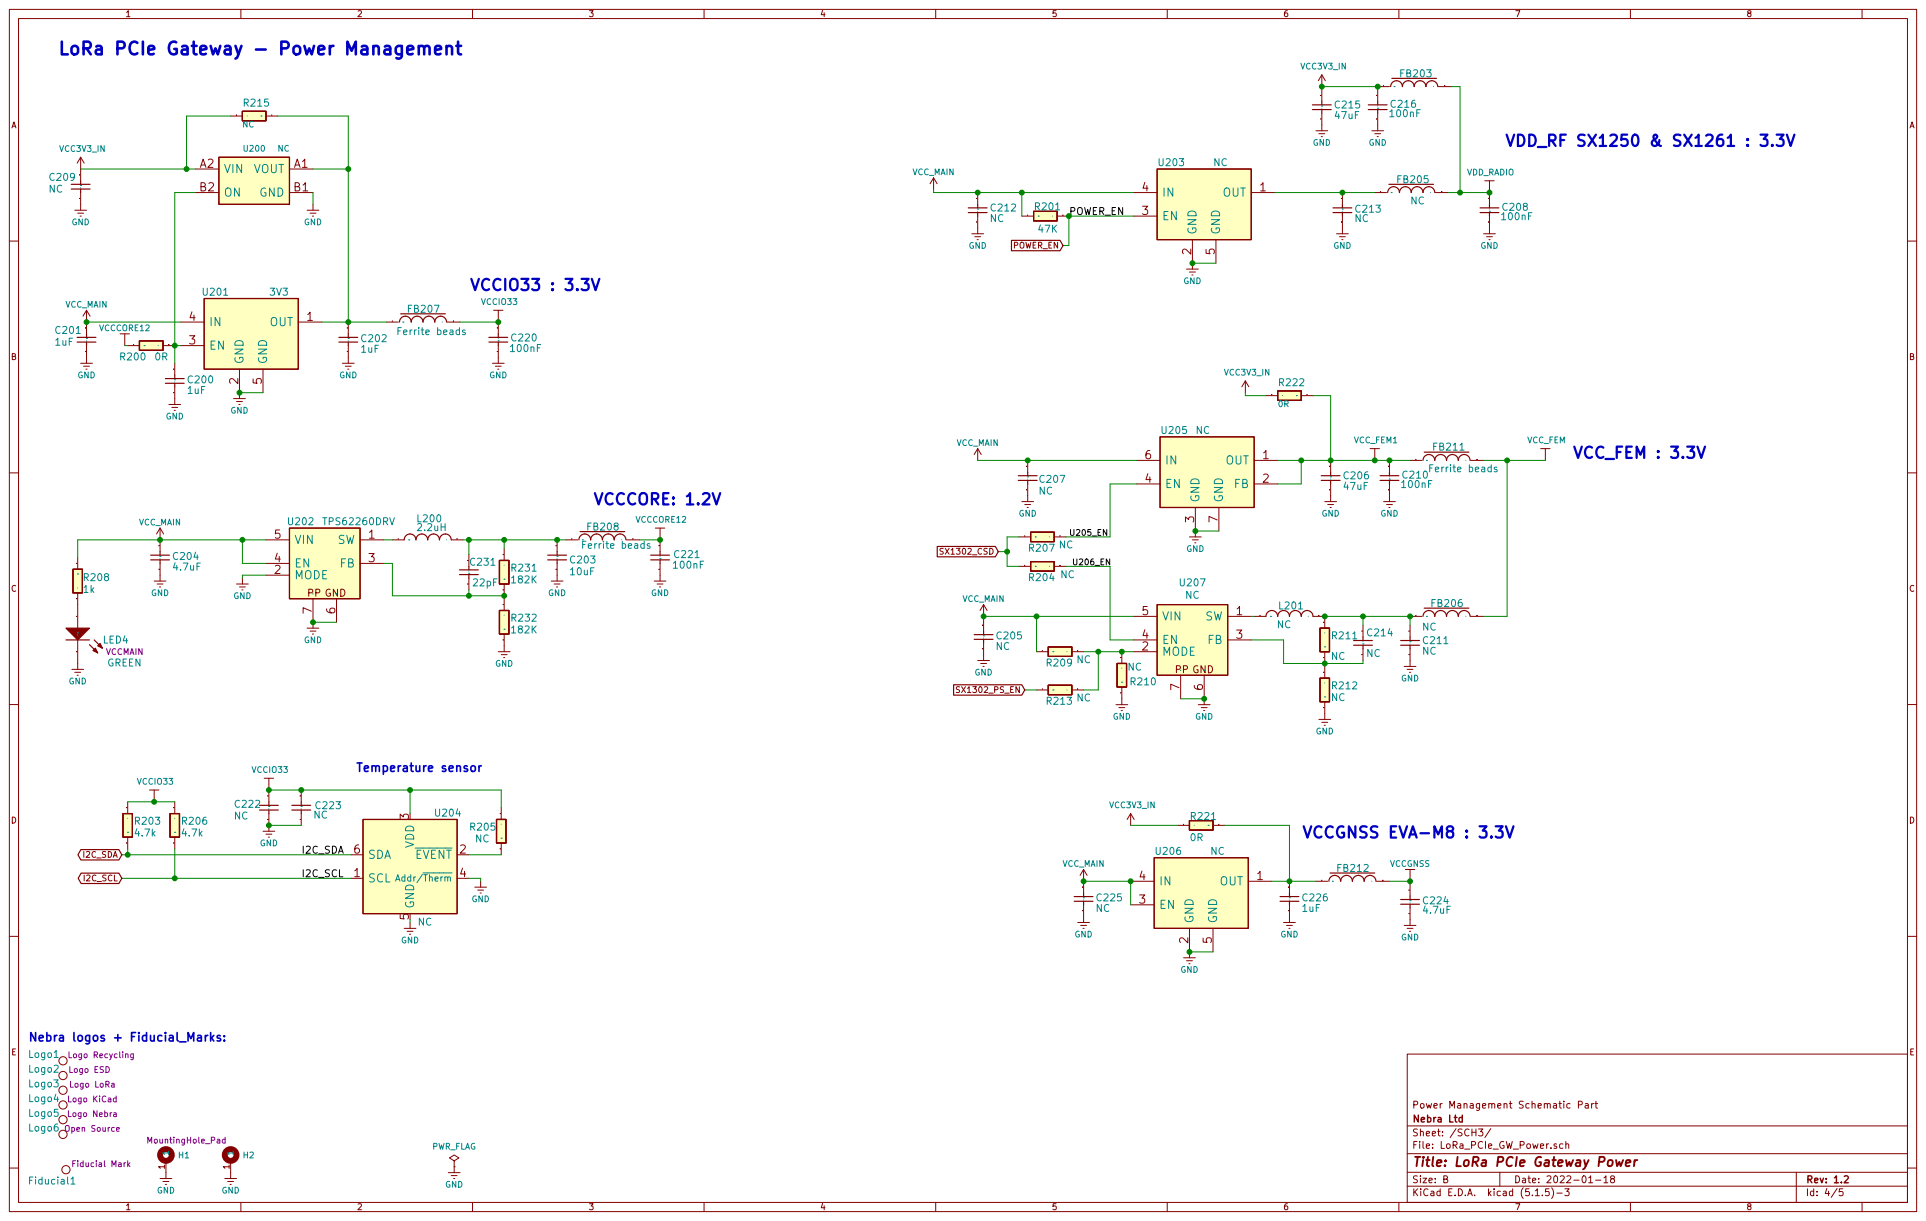
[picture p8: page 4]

LoRa PCIe Gateway - Power Management

File: LoRa_PCIe_GW_Power.sch Sheet: /SCH3/ Nebra Ltd Power Management Schematic Part

Id: 4/5 Title: LoRa PCIe Gateway Power

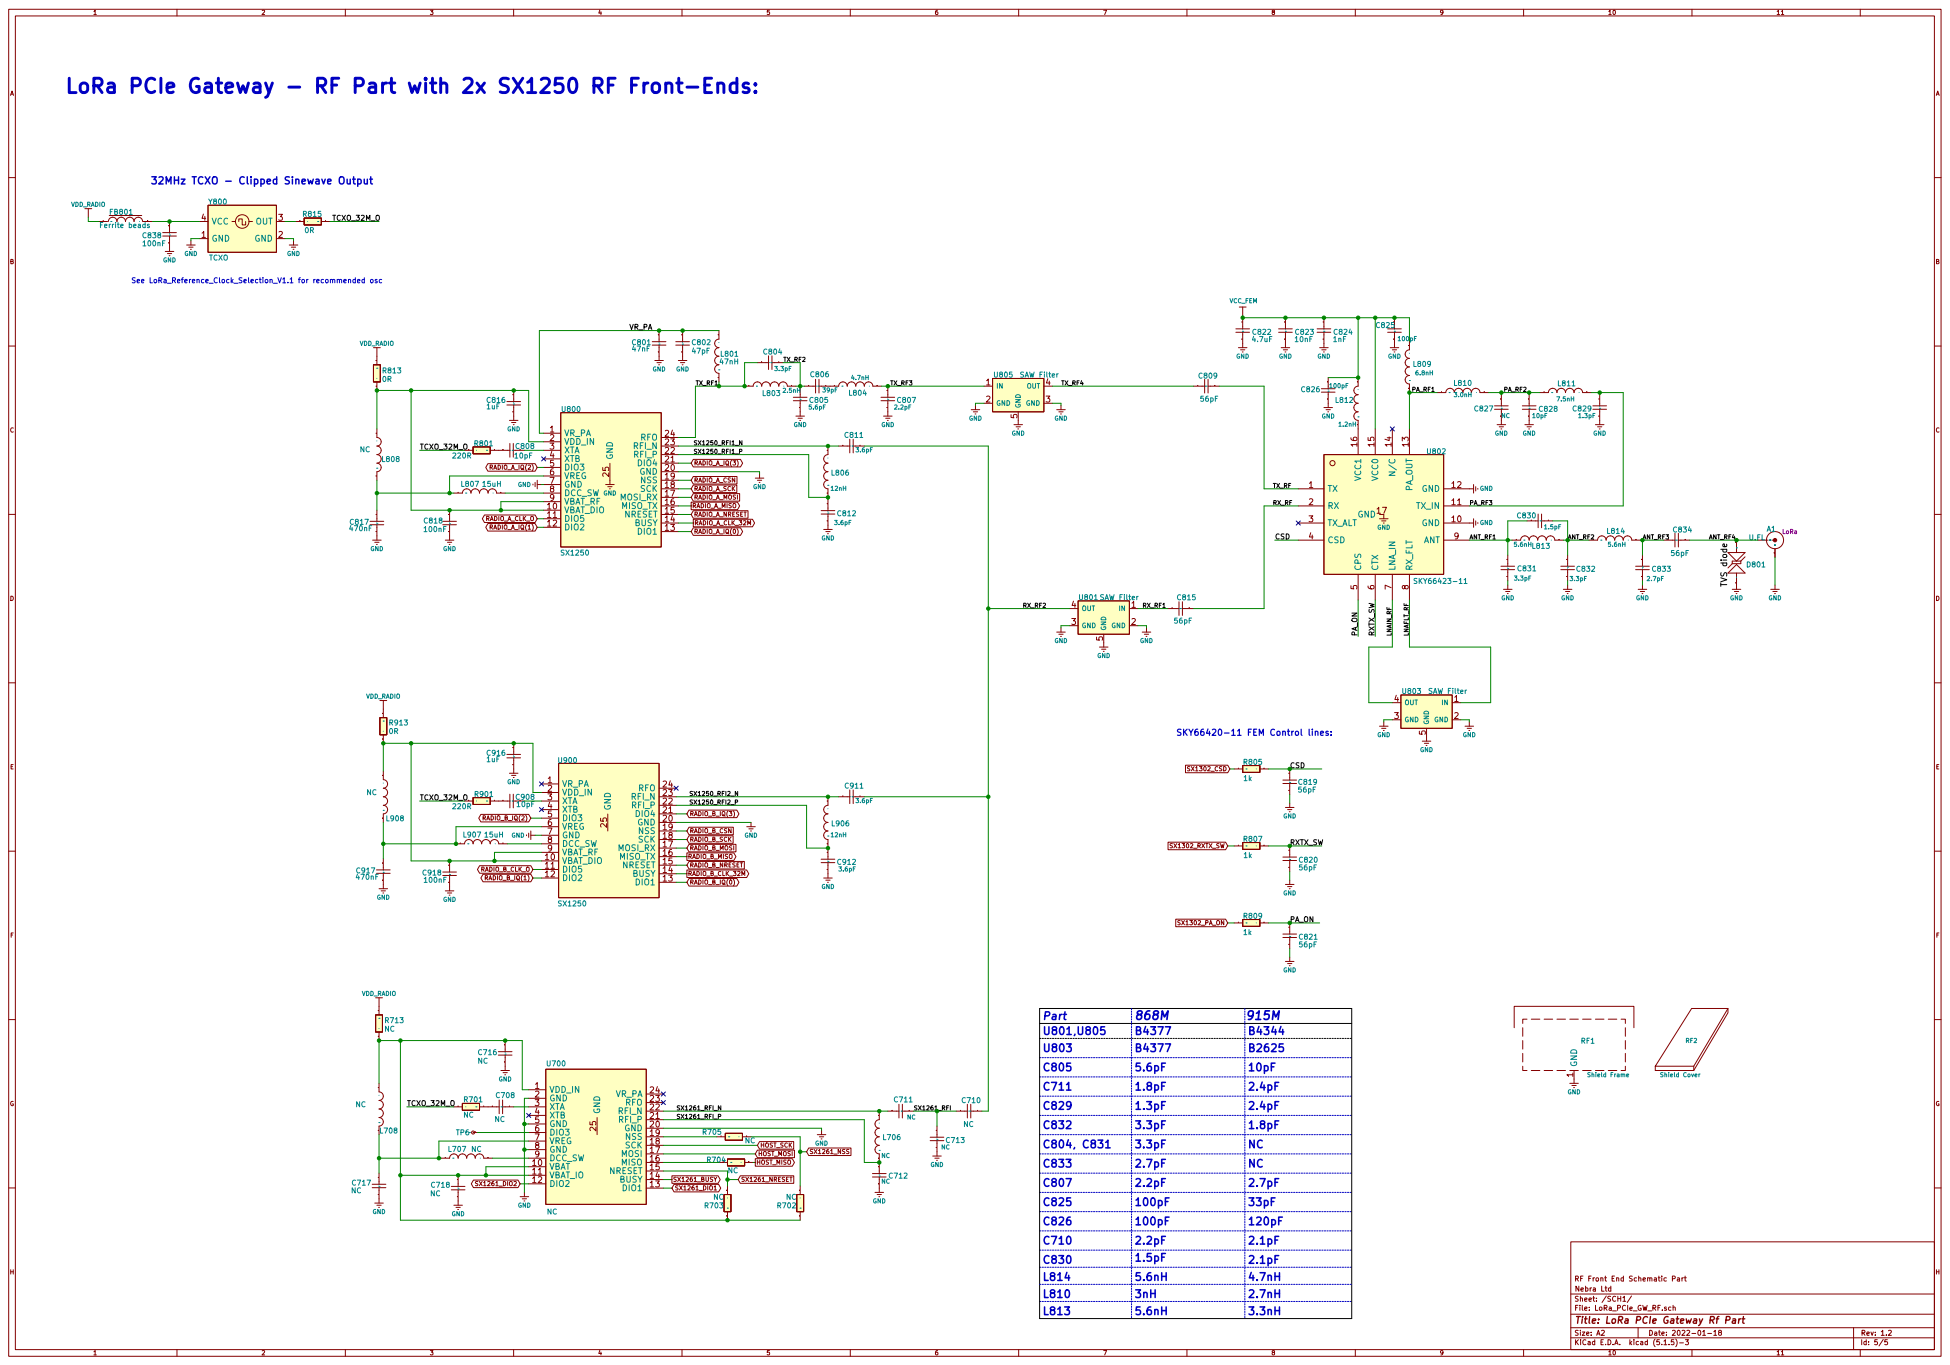
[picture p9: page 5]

LoRa PCIe Gateway - RF Part with 2x SX1250 RF Front-Ends:

32MHz TCXO - Clipped Sinewave Output

See LoRa_Reference_Clock_Selection_V1.1 for recommended osc

Part | 868M
U801,U805
U803 | B4377 | B2625

1 | GND 8

C825
C826

File: LoRa_PCIe_GW_RF.sch Sheet: /SCH1/ Nebra Ltd RF Front End Schematic Part

L810
L813

Id: 5/5 Title: LoRa PCIe Gateway Rf Part

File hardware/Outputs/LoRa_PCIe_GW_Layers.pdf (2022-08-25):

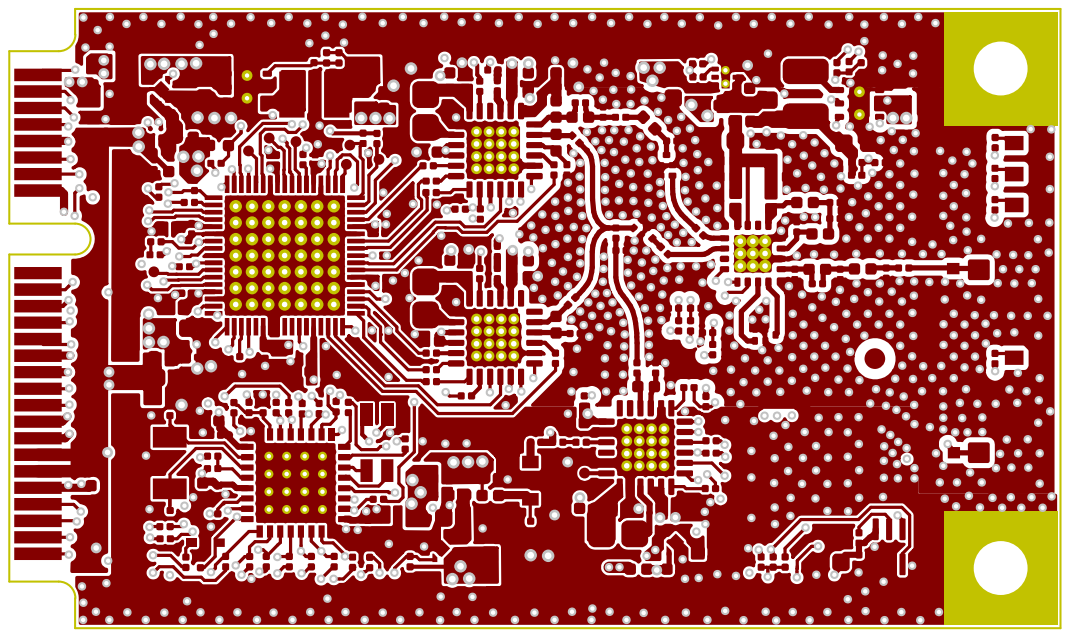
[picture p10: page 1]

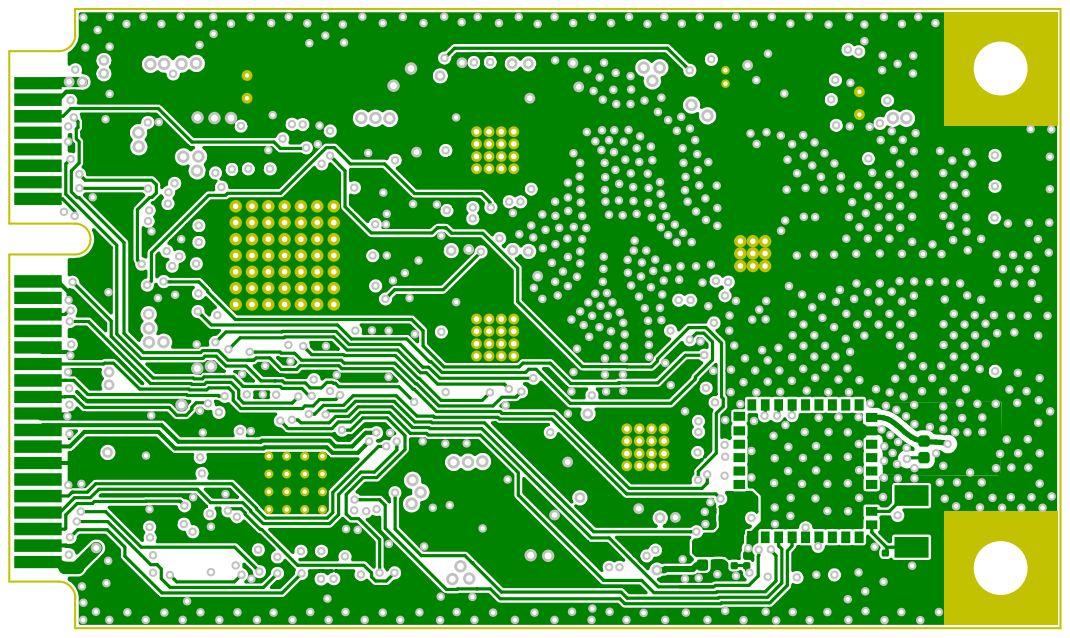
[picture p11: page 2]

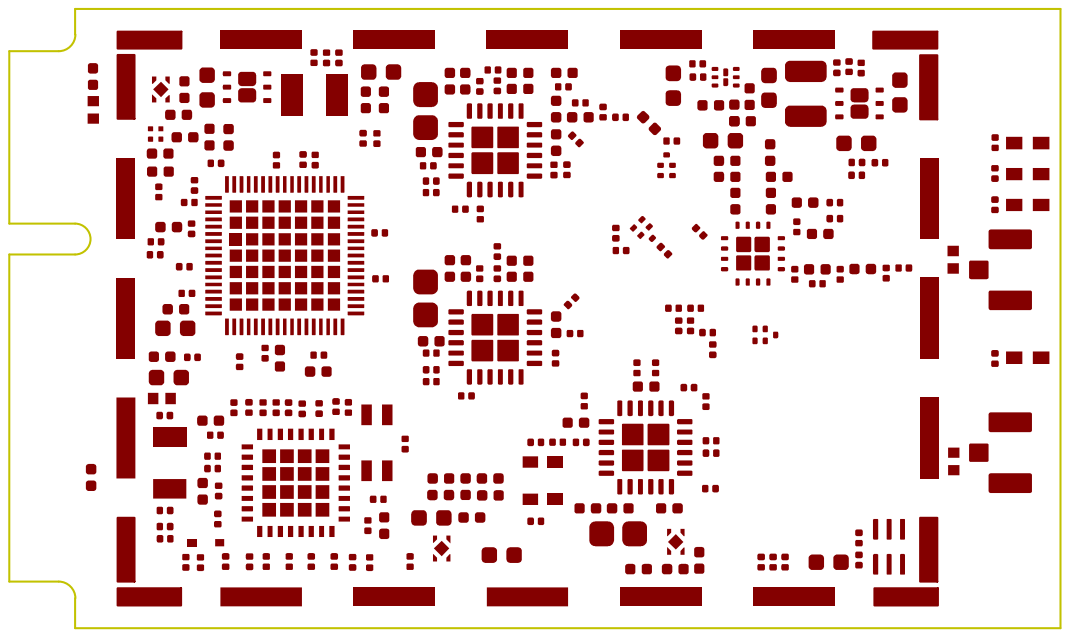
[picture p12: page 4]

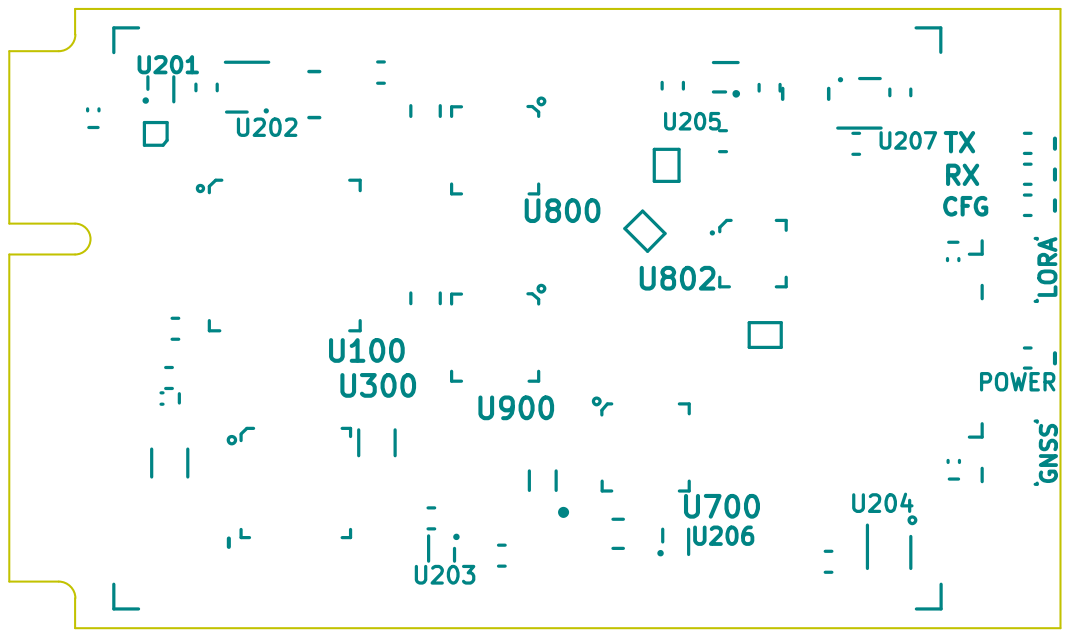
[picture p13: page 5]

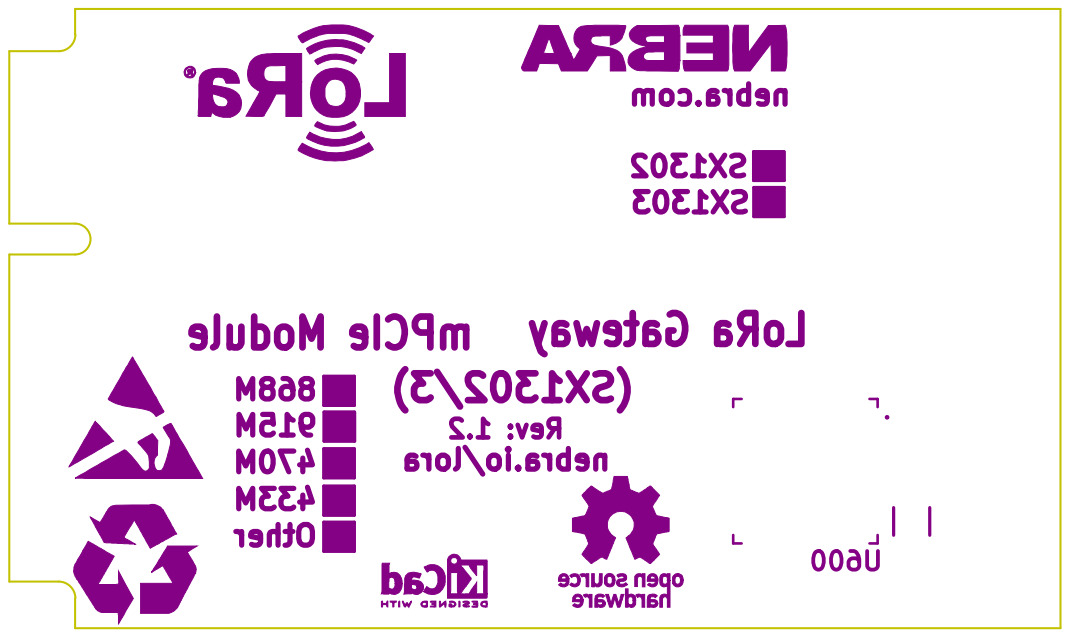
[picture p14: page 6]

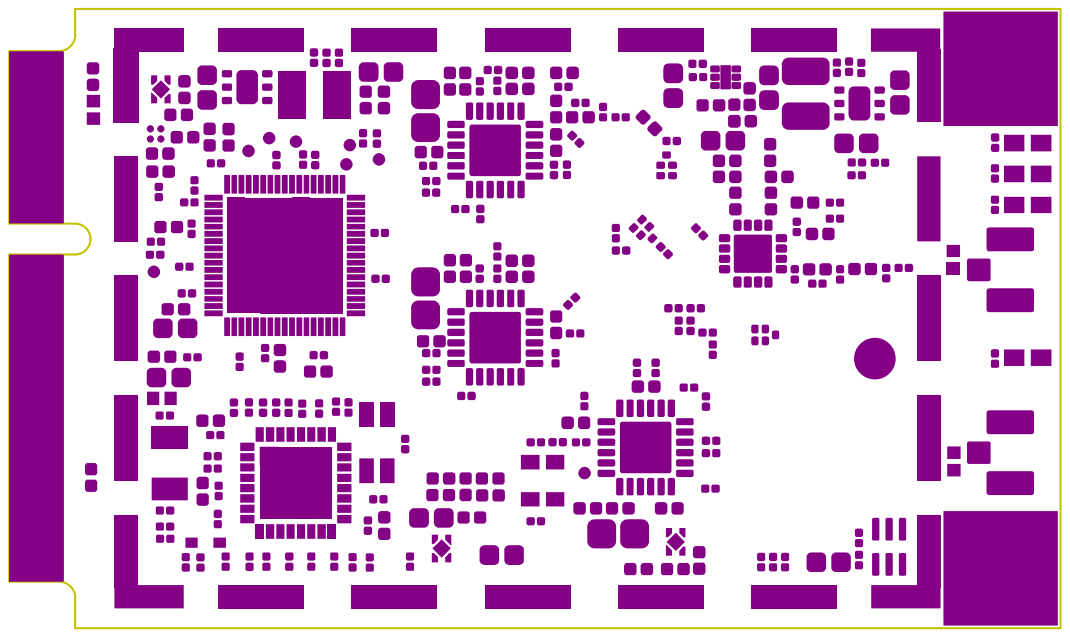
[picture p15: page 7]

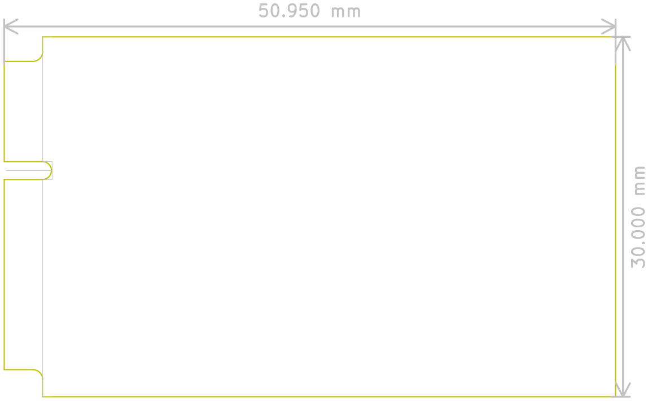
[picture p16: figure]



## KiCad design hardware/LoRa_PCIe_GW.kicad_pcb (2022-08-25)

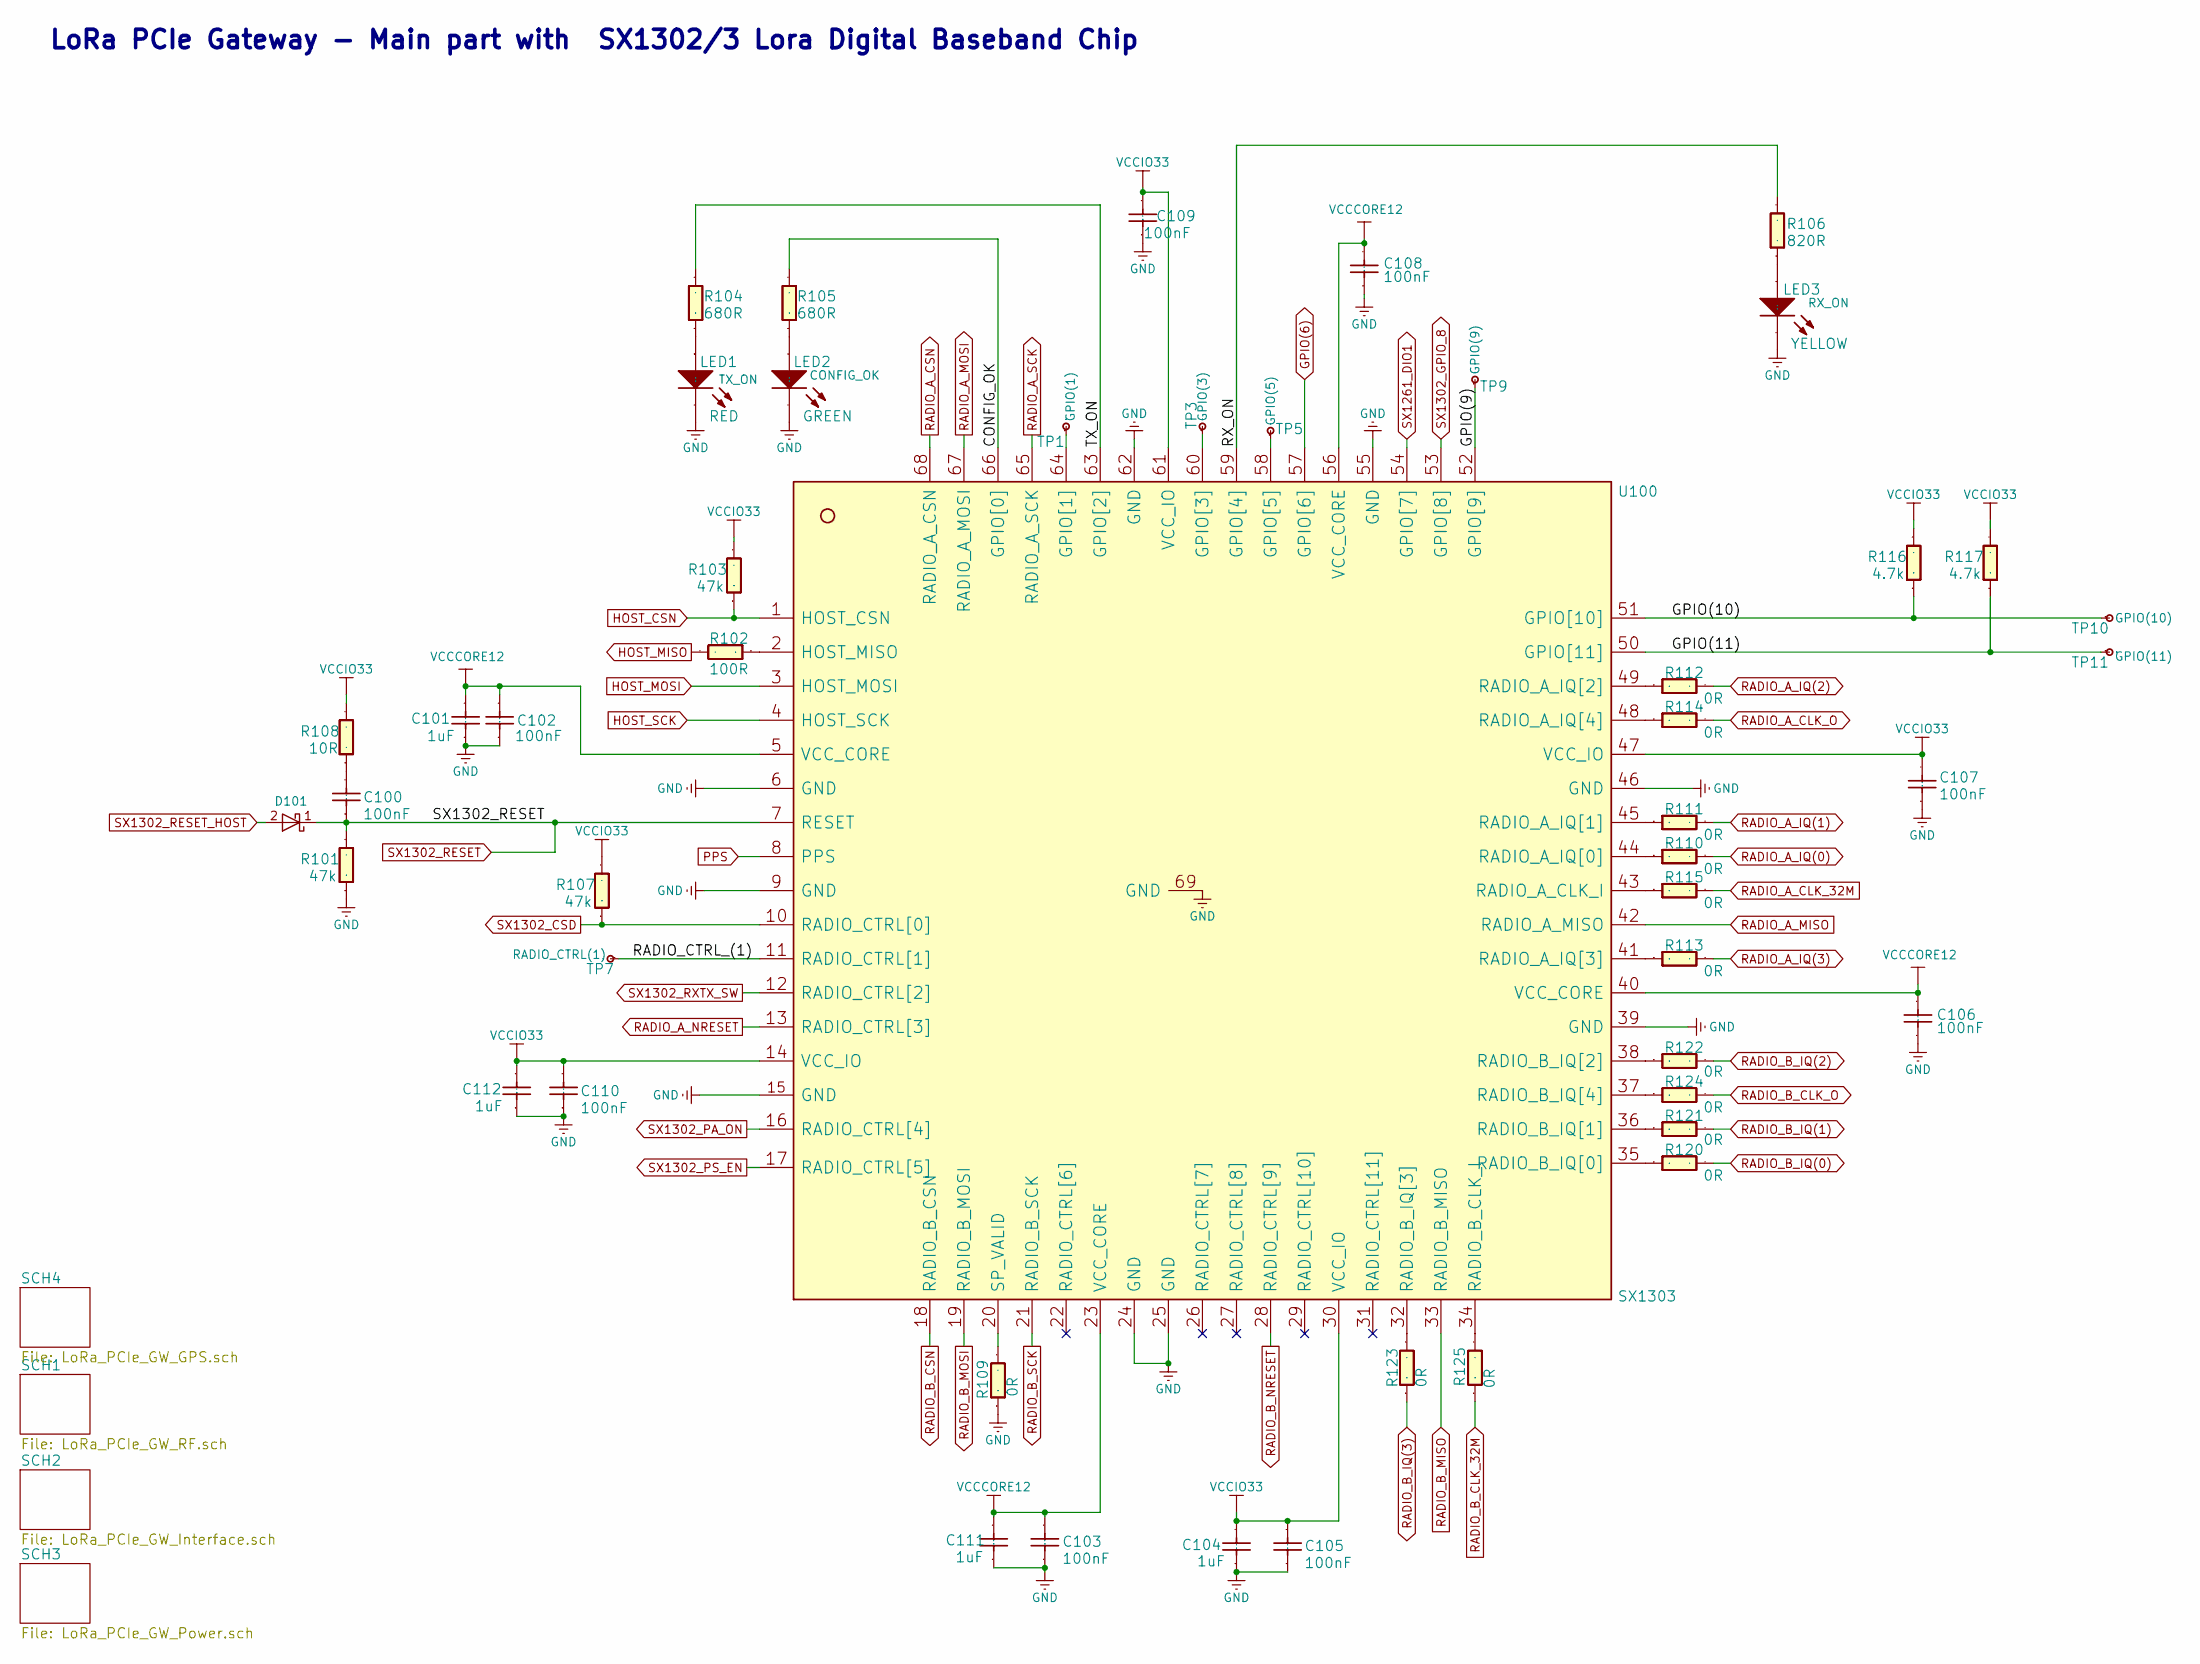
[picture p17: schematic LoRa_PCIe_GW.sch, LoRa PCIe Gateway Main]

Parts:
C100, C102, C103, C105, C106, C107, C108, C109, C110: 100nF; ccer_201_smd_small; Part Number GRM033C71C104KE14D
C101, C104, C111, C112: 1uF; ccer_402_smd_small; Part Number GRM153R61A105ME95D
D101: BAT54; SOD523; Part Number BAT54XV2T1G
LED1: RED; CD1005-0402-RED; Part Number APHHS1005SURCK
LED2: GREEN; CD1005-0402; Part Number APHHS1005LCGCK
LED3: YELLOW; CD1005-0402-YELLOW; Part Number APHHS1005LSYCK/J3-PF
R101, R103, R107: 47k; rlc_201_smd_small; Part Number CRCW020147K0
R102: 100R; rlc_201_smd_small; Part Number CRCW0201100R
R104, R105: 680R; rlc_201_smd_small; Part Number CRCW0201680R
R106: 820R; rlc_201_smd_small; Part Number CRCW0201820R
R108: 10R; rlc_201_smd_small; Part Number CRCW020110R0JNED
R109, R110, R111, R112, R113, R114, R115, R120, R121, R122, R123, R124, R125: 0R; rlc_201_smd_small; Part Number CRCW02010000Z0ED
R116, R117: 4.7k; rlc_201_smd_small; Part Number CRCW02014K70FNED
TP1, TP3, TP5, TP7, TP9, TP10, TP11: NC; PIN_SMD
U100: SX1303; vqfn68_7x7mm; Part Number SX1303IMLTRT

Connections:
/CONFIG_OK: R105.2, U100.66 (GPIO[0])
/GPIO(9): TP9.1, U100.52 (GPIO[9])
/GPIO(10): R116.1, TP10.1, U100.51 (GPIO[10])
/GPIO(11): R117.1, TP11.1, U100.50 (GPIO[11])
/RADIO_CTRL_(1): TP7.1, U100.11 (RADIO_CTRL[1])
/RX_ON: R106.2, U100.59 (GPIO[4])
/TX_ON: R104.2, U100.63 (GPIO[2])
GND: C101.1, C102.1, C103.1, C104.1, C105.1, C106.1, C107.1, C108.1, C109.1, C110.1, C111.1, C112.1, LED1.2 (K), LED2.2 (K), LED3.2 (K), R101.1, R109.1, U100.6 (GND), U100.9 (GND), U100.15 (GND), U100.24 (GND), U100.25 (GND), U100.39 (GND), U100.46 (GND), U100.55 (GND), U100.62 (GND), U100.69 (GND); also elsewhere on the board
GPIO(6): U100.57 (GPIO[6]); also elsewhere on the board
HOST_CSN: R103.1, U100.1 (HOST_CSN); also elsewhere on the board
HOST_MISO: R102.2; also elsewhere on the board
HOST_MOSI: U100.3 (HOST_MOSI); also elsewhere on the board
HOST_SCK: U100.4 (HOST_SCK); also elsewhere on the board
unnamed: C100.2, R108.1
unnamed: LED1.1 (A), R104.1
unnamed: LED2.1 (A), R105.1
unnamed: LED3.1 (A), R106.1
unnamed: R102.1, U100.2 (HOST_MISO)
unnamed: R109.2, U100.20 (SP_VALID)
unnamed: R110.1, U100.44 (RADIO_A_IQ[0])
unnamed: R111.1, U100.45 (RADIO_A_IQ[1])
unnamed: R112.1, U100.49 (RADIO_A_IQ[2])
unnamed: R113.1, U100.41 (RADIO_A_IQ[3])
unnamed: R114.1, U100.48 (RADIO_A_IQ[4])
unnamed: R115.1, U100.43 (RADIO_A_CLK_I)
unnamed: R120.1, U100.35 (RADIO_B_IQ[0])
unnamed: R121.1, U100.36 (RADIO_B_IQ[1])
unnamed: R122.1, U100.38 (RADIO_B_IQ[2])
unnamed: R123.2, U100.32 (RADIO_B_IQ[3])
unnamed: R124.1, U100.37 (RADIO_B_IQ[4])
unnamed: R125.2, U100.34 (RADIO_B_CLK_I)
unnamed: TP1.1, U100.64 (GPIO[1])
unnamed: TP3.1, U100.60 (GPIO[3])
unnamed: TP5.1, U100.58 (GPIO[5])
PPS: U100.8 (PPS); also elsewhere on the board
RADIO_A_CLK_32M: R115.2; also elsewhere on the board
RADIO_A_CLK_O: R114.2; also elsewhere on the board
RADIO_A_CSN: U100.68 (RADIO_A_CSN); also elsewhere on the board
RADIO_A_IQ(0): R110.2; also elsewhere on the board
RADIO_A_IQ(1): R111.2; also elsewhere on the board
RADIO_A_IQ(2): R112.2; also elsewhere on the board
RADIO_A_IQ(3): R113.2; also elsewhere on the board
RADIO_A_MISO: U100.42 (RADIO_A_MISO); also elsewhere on the board
RADIO_A_MOSI: U100.67 (RADIO_A_MOSI); also elsewhere on the board
RADIO_A_NRESET: U100.13 (RADIO_CTRL[3]); also elsewhere on the board
RADIO_A_SCK: U100.65 (RADIO_A_SCK); also elsewhere on the board
RADIO_B_CLK_32M: R125.1; also elsewhere on the board
RADIO_B_CLK_O: R124.2; also elsewhere on the board
RADIO_B_CSN: U100.18 (RADIO_B_CSN); also elsewhere on the board
RADIO_B_IQ(0): R120.2; also elsewhere on the board
RADIO_B_IQ(1): R121.2; also elsewhere on the board
RADIO_B_IQ(2): R122.2; also elsewhere on the board
RADIO_B_IQ(3): R123.1; also elsewhere on the board
RADIO_B_MISO: U100.33 (RADIO_B_MISO); also elsewhere on the board
RADIO_B_MOSI: U100.19 (RADIO_B_MOSI); also elsewhere on the board
RADIO_B_NRESET: U100.28 (RADIO_CTRL[9]); also elsewhere on the board
RADIO_B_SCK: U100.21 (RADIO_B_SCK); also elsewhere on the board
SX1261_DIO1: U100.54 (GPIO[7]); also elsewhere on the board
SX1302_CSD: R107.1, U100.10 (RADIO_CTRL[0]); also elsewhere on the board
SX1302_GPIO_8: U100.53 (GPIO[8]); also elsewhere on the board
SX1302_PA_ON: U100.16 (RADIO_CTRL[4]); also elsewhere on the board
SX1302_PS_EN: U100.17 (RADIO_CTRL[5]); also elsewhere on the board
SX1302_RESET: C100.1, D101.1, R101.2, U100.7 (RESET); also elsewhere on the board
SX1302_RESET_HOST: D101.2; also elsewhere on the board
SX1302_RXTX_SW: U100.12 (RADIO_CTRL[2]); also elsewhere on the board
VCCCORE12: C101.2, C102.2, C103.2, C106.2, C108.2, C111.2, U100.5 (VCC_CORE), U100.23 (VCC_CORE), U100.40 (VCC_CORE), U100.56 (VCC_CORE); also elsewhere on the board
VCCIO33: C104.2, C105.2, C107.2, C109.2, C110.2, C112.2, R103.2, R107.2, R108.2, R116.2, R117.2, U100.14 (VCC_IO), U100.30 (VCC_IO), U100.47 (VCC_IO), U100.61 (VCC_IO); also elsewhere on the board

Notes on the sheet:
LoRa PCIe Gateway - Main part with SX1302/3 Lora Digital Baseband Chip

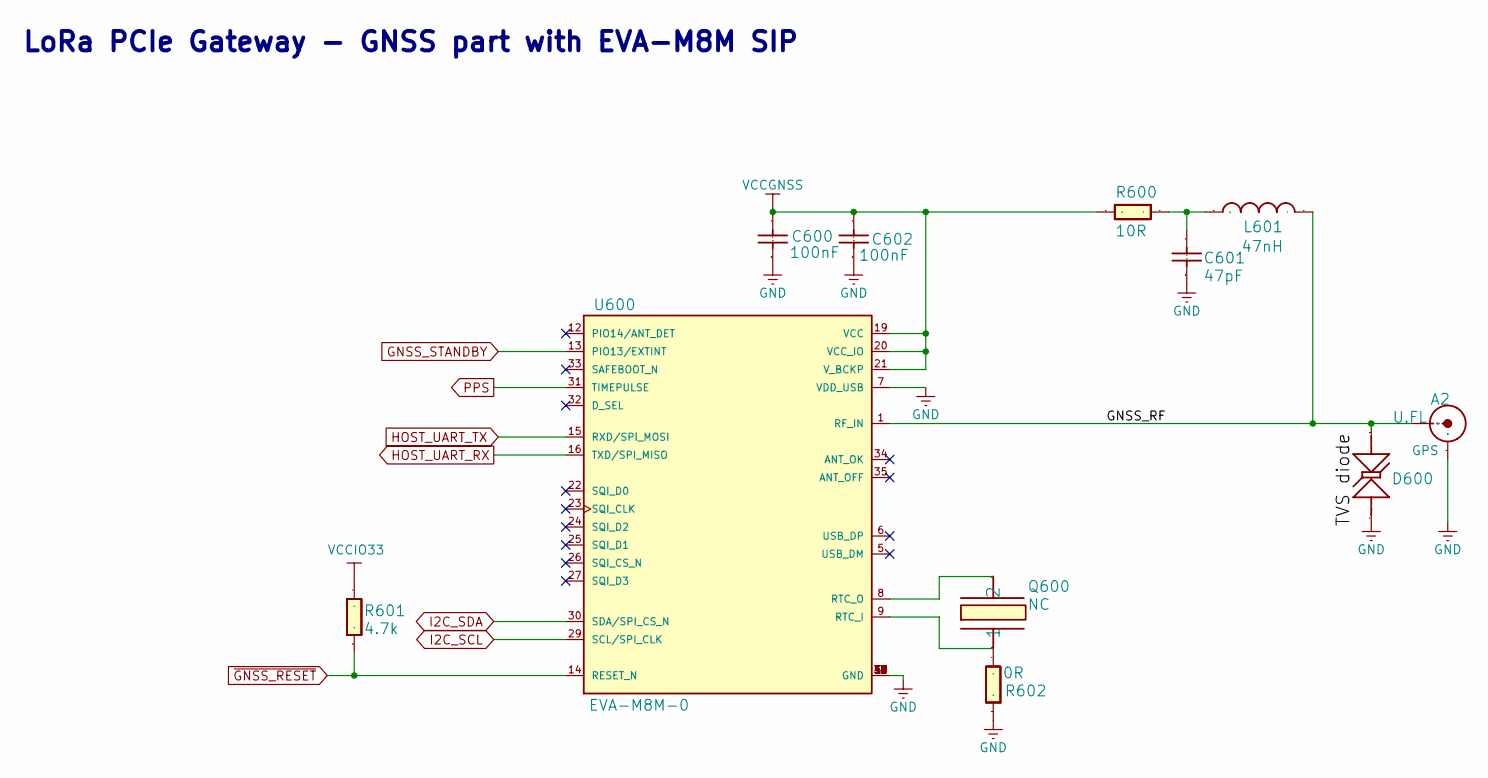
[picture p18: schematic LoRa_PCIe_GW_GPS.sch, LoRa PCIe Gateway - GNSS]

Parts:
A2: U.FL; U.FL-R-SMT_Hirose; Part Number U.FL-R-SMT-1(80)
C600, C602: 100nF; ccer_201_smd_small; Part Number GRM033C71C104KE14D
C601: 47pF; ccer_201_smd_small; Part Number GRM0335C1H470JA01D
D600: SLP1006P2T; Part Number LXES15AAA1-153
L601: 47nH; rlc_402_smd_small; Part Number LQW15AN47NJ00D
Q600: NC; XTAL_3215_SMD; Part Number NX3215SA-32.768K-STD-MUA-9
R600: 10R; rlc_201_smd_small; Part Number CRCW020110R0FNED
R601: 4.7k; rlc_201_smd_small; Part Number CRCW02014K70FNED
R602: 0R; rlc_201_smd_small; Part Number CRCW02010000Z0ED
U600: EVA-M8M-0; LGA43R65P9X9_700X700X116; Part Number EVA-M8M-0

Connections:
/SCH4/GNSS_RF: A2.1 (Signal), D600.1 (A), L601.2, U600.1 (RF_IN)
GND: A2.2 (GND), A2.3 (GND), C600.1, C601.1, C602.1, D600.2 (K), R602.1, U600.2 (GND), U600.7 (VDD_USB), U600.18 (GND), U600.37 (GND), U600.38 (GND), U600.39 (GND), U600.40 (GND), U600.41 (GND), U600.42 (GND), U600.43 (GND); also elsewhere on the board
GNSS_STANDBY: U600.13 (PIO13/EXTINT); also elsewhere on the board
HOST_UART_RX: U600.16 (TXD/SPI_MISO); also elsewhere on the board
HOST_UART_TX: U600.15 (RXD/SPI_MOSI); also elsewhere on the board
I2C_SCL: U600.29 (SCL/SPI_CLK); also elsewhere on the board
I2C_SDA: U600.30 (SDA/SPI_CS_N); also elsewhere on the board
unnamed: C601.2, L601.1, R600.2
unnamed: Q600.1, R602.2, U600.9 (RTC_I)
unnamed: Q600.2, U600.8 (RTC_O)
PPS: U600.31 (TIMEPULSE); also elsewhere on the board
VCCGNSS: C600.2, C602.2, R600.1, U600.19 (VCC), U600.20 (VCC_IO), U600.21 (V_BCKP); also elsewhere on the board
VCCIO33: R601.2; also elsewhere on the board
~GNSS_RESET~: R601.1, U600.14 (RESET_N); also elsewhere on the board

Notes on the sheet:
LoRa PCIe Gateway - GNSS part with EVA-M8M SIP

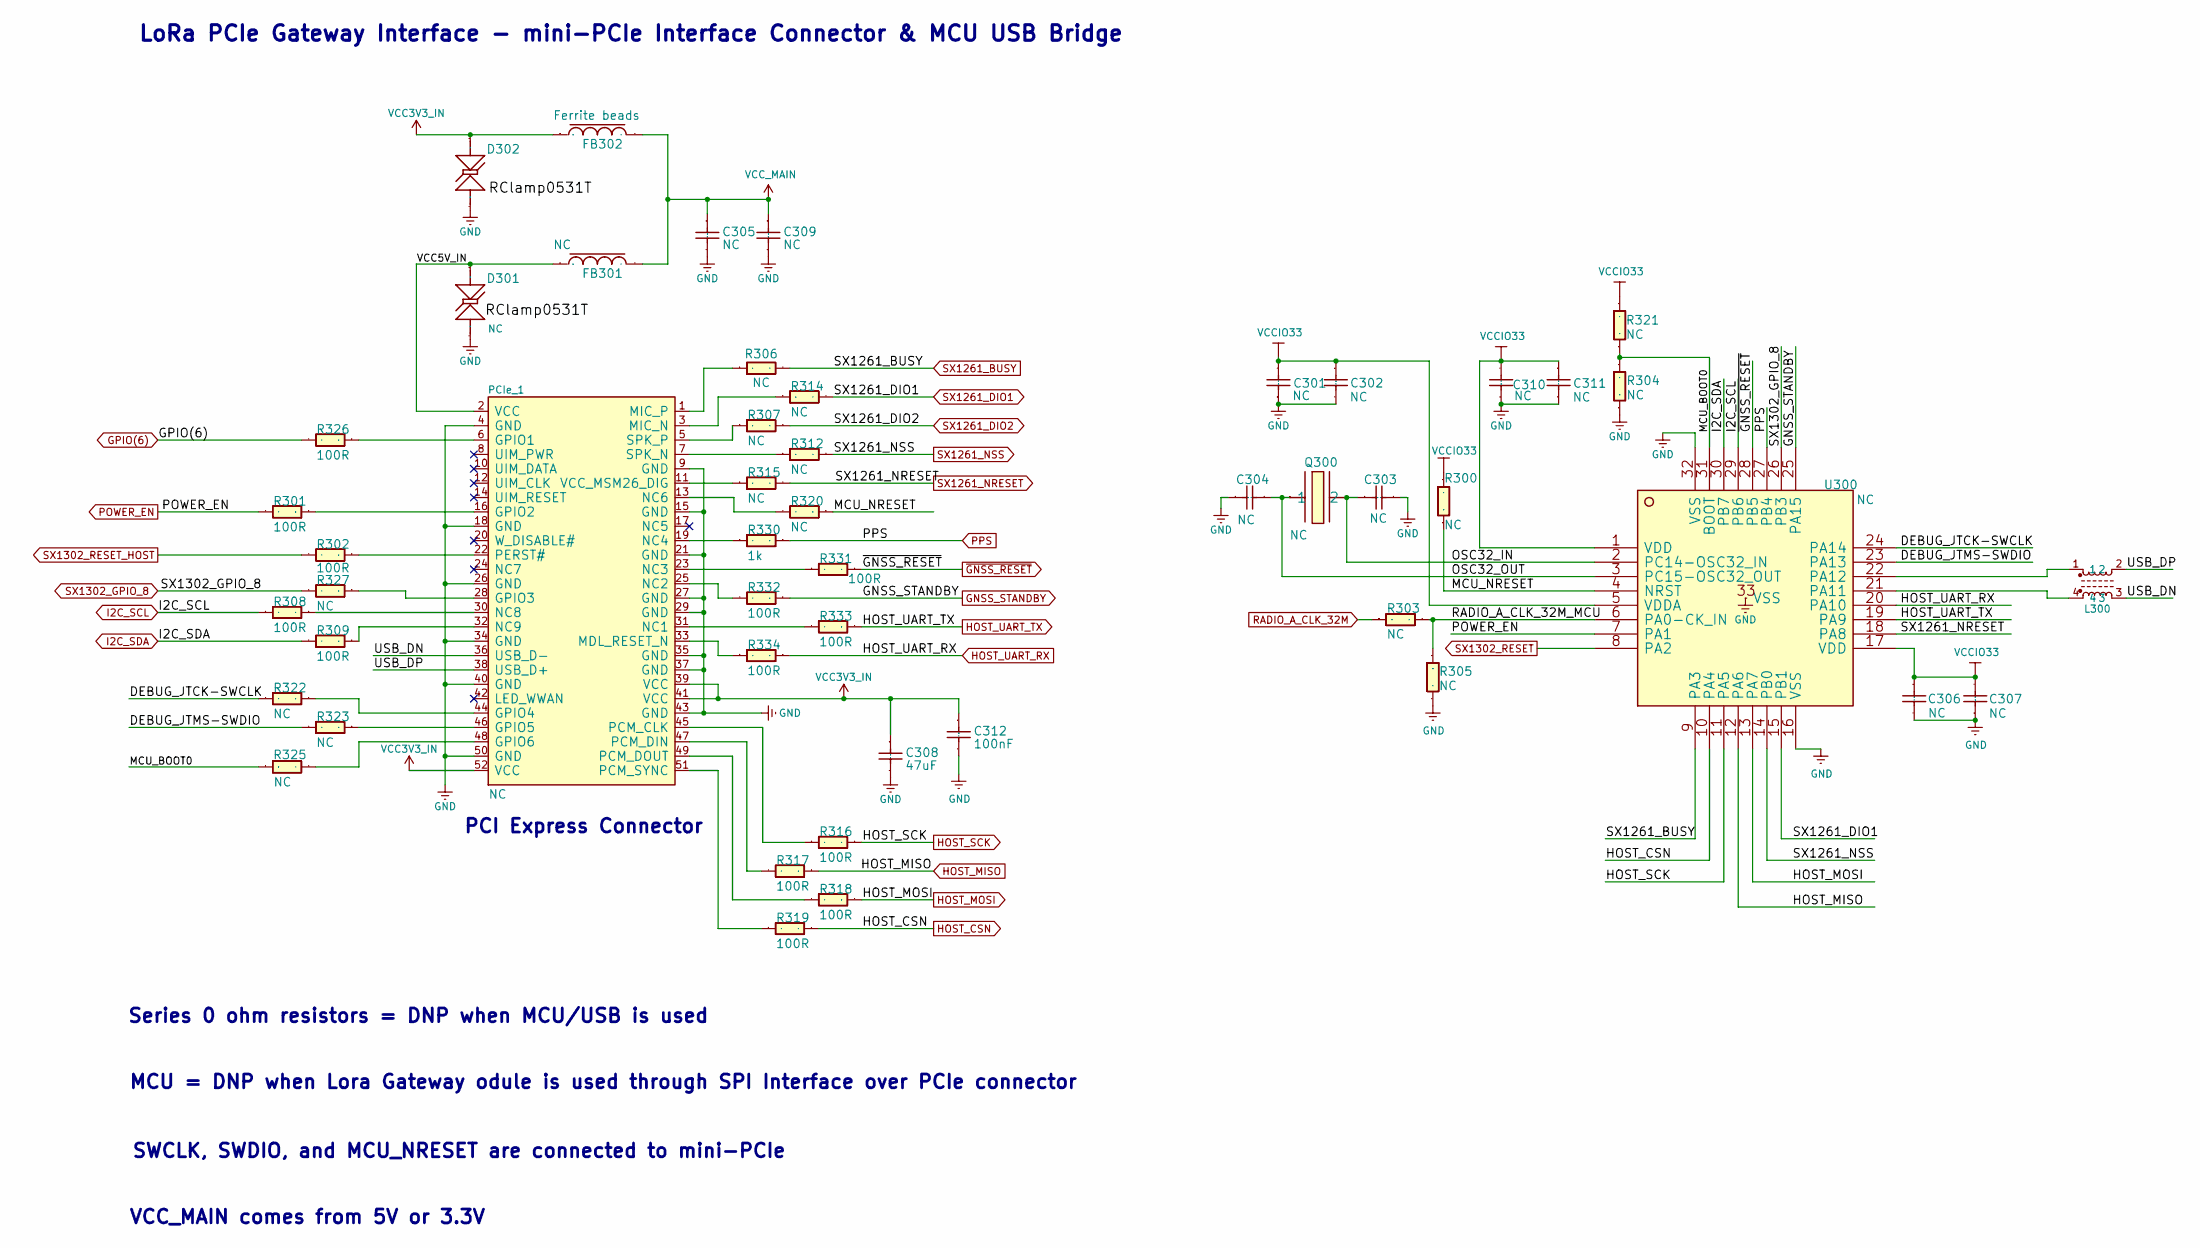
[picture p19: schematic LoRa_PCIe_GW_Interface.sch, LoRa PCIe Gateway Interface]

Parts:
C301, C307, C310: NC; rlc_402_smd_small
C302, C303, C304, C306, C311: NC; rlc_201_smd_small
C305: NC; ccer_603_smd_small; Part Number GRM188R60J476ME15D
C308: 47uF; ccer_603_smd_small; Part Number GRM188R60J476ME15D
C309: NC; ccer_201_smd_small; Part Number GRM033C71C104KE14D
C312: 100nF; ccer_402_smd_small; Part Number GMD155R71C104KA11
D301: NC; SLP1006P2T; Part Number RCLAMP0531T.TCT
D302: 20V; SLP1006P2T; Part Number RCLAMP0531T.TCT
FB301: NC; rlc_402_smd_small; Part Number BLM15PG100SN1D
FB302: Ferrite beads; rlc_402_smd_small; Part Number BLM15PG100SN1D
L300: NC; IND_744232090; Part Number 744232090
PCIe_1: NC; PCIeMini-GF-2D-800-1K-S52
Q300: NC; XTAL_3215_SMD; Part Number NX3215SA-32.768K-STD-MUA-9
R300: NC; rlc_201_smd_small; Part Number CRCW020147K0
R301, R302, R308, R309, R316, R317, R318, R319, R326, R331, R332, R333, R334: 100R; rlc_201_smd_small; Part Number CRCW0201100R
R303, R304, R305, R321: NC; rlc_201_smd_small
R306, R307, R312, R314, R315, R320, R322, R323, R325: NC; rlc_201_smd_small; Part Number CRCW02011K00JNED
R327: NC; rlc_201_smd_small; Part Number CRCW0201100R
R330: 1k; rlc_201_smd_small; Part Number CRCW02011K00JNED
U300: NC; UFQFPN32_5x5mm; Part Number STM32L412Kx

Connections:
/SCH2/DEBUG_JTCK-SWCLK: R322.2, U300.24 (PA14)
/SCH2/DEBUG_JTMS-SWDIO: R323.2, U300.23 (PA13)
/SCH2/MCU_BOOT0: R304.2, R321.1, R325.1, U300.31 (BOOT)
/SCH2/MCU_NRESET: R300.1, R320.1, U300.4 (NRST)
/SCH2/OSC32_IN: C303.1, Q300.2, U300.2 (PC14-OSC32_IN)
/SCH2/OSC32_OUT: C304.2, Q300.1, U300.3 (PC15-OSC32_OUT)
/SCH2/RADIO_A_CLK_32M_MCU: R303.2, R305.1, U300.6 (PA0-CK_IN)
/SCH2/USB_DN: L300.3, PCIe_1.36 (USB_D-)
/SCH2/USB_DP: L300.2, PCIe_1.38 (USB_D+)
/SCH2/VCC5V_IN: D301.1 (A), FB301.1, PCIe_1.2 (VCC)
GND: C301.1, C302.2, C303.2, C304.1, C305.2, C306.2, C307.1, C308.2, C309.2, C310.1, C311.2, C312.2, D301.2 (K), D302.2 (K), PCIe_1.4 (GND), PCIe_1.9 (GND), PCIe_1.15 (GND), PCIe_1.18 (GND), PCIe_1.21 (GND), PCIe_1.26 (GND), PCIe_1.27 (GND), PCIe_1.29 (GND), PCIe_1.34 (GND), PCIe_1.35 (GND), PCIe_1.37 (GND), PCIe_1.40 (GND), PCIe_1.43 (GND), PCIe_1.50 (GND), R304.1, R305.2, U300.16 (VSS), U300.32 (VSS), U300.33 (VSS); also elsewhere on the board
GNSS_STANDBY: R332.1, U300.25 (PA15); also elsewhere on the board
GPIO(6): R326.2; also elsewhere on the board
HOST_CSN: R319.1, U300.10 (PA4); also elsewhere on the board
HOST_MISO: R317.1, U300.12 (PA6); also elsewhere on the board
HOST_MOSI: R318.1, U300.13 (PA7); also elsewhere on the board
HOST_SCK: R316.1, U300.11 (PA5); also elsewhere on the board
HOST_UART_RX: R334.1, U300.20 (PA10); also elsewhere on the board
HOST_UART_TX: R333.1, U300.19 (PA9); also elsewhere on the board
I2C_SCL: R308.2, U300.29 (PB6); also elsewhere on the board
I2C_SDA: R309.2, U300.30 (PB7); also elsewhere on the board
unnamed: L300.1, U300.22 (PA12)
unnamed: L300.4, U300.21 (PA11)
unnamed: PCIe_1.1 (MIC_P), R306.1
unnamed: PCIe_1.3 (MIC_N), R314.1
unnamed: PCIe_1.5 (SPK_P), R307.1
unnamed: PCIe_1.6 (GPIO1), R326.1
unnamed: PCIe_1.7 (SPK_N), R312.1
unnamed: PCIe_1.11 (VCC_MSM26_DIG), R315.1
unnamed: PCIe_1.13 (NC6), R320.2
unnamed: PCIe_1.16 (GPIO2), R301.1
unnamed: PCIe_1.19 (NC4), R330.2
unnamed: PCIe_1.22 (PERST#), R302.1
unnamed: PCIe_1.23 (NC3), R331.2
unnamed: PCIe_1.25 (NC2), R332.2
unnamed: PCIe_1.28 (GPIO3), R327.1
unnamed: PCIe_1.30 (NC8), R308.1
unnamed: PCIe_1.31 (NC1), R333.2
unnamed: PCIe_1.32 (NC9), R309.1
unnamed: PCIe_1.33 (MDL_RESET_N), R334.2
unnamed: PCIe_1.44 (GPIO4), R322.1
unnamed: PCIe_1.45 (PCM_CLK), R316.2
unnamed: PCIe_1.46 (GPIO5), R323.1
unnamed: PCIe_1.47 (PCM_DIN), R317.2
unnamed: PCIe_1.48 (GPIO6), R325.2
unnamed: PCIe_1.49 (PCM_DOUT), R318.2
unnamed: PCIe_1.51 (PCM_SYNC), R319.2
POWER_EN: R301.2, U300.7 (PA1); also elsewhere on the board
PPS: R330.1, U300.27 (PB4); also elsewhere on the board
RADIO_A_CLK_32M: R303.1; also elsewhere on the board
SX1261_BUSY: R306.2, U300.9 (PA3); also elsewhere on the board
SX1261_DIO1: R314.2, U300.15 (PB1); also elsewhere on the board
SX1261_DIO2: R307.2; also elsewhere on the board
SX1261_NRESET: R315.2, U300.18 (PA8); also elsewhere on the board
SX1261_NSS: R312.2, U300.14 (PB0); also elsewhere on the board
SX1302_GPIO_8: R327.2, U300.26 (PB3); also elsewhere on the board
SX1302_RESET: U300.8 (PA2); also elsewhere on the board
SX1302_RESET_HOST: R302.2; also elsewhere on the board
VCC3V3_IN: C308.1, C312.1, D302.1 (A), FB302.1, PCIe_1.39 (VCC), PCIe_1.41 (VCC), PCIe_1.52 (VCC); also elsewhere on the board
VCCIO33: C301.2, C302.1, C306.1, C307.2, C310.2, C311.1, R300.2, R321.2, U300.1 (VDD), U300.5 (VDDA), U300.17 (VDD); also elsewhere on the board
VCC_MAIN: C305.1, C309.1, FB301.2, FB302.2; also elsewhere on the board
~GNSS_RESET~: R331.1, U300.28 (PB5); also elsewhere on the board

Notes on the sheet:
LoRa PCIe Gateway Interface - mini-PCIe Interface Connector & MCU USB Bridge
PCI Express Connector
Series 0 ohm resistors = DNP when MCU/USB is used
MCU = DNP when Lora Gateway odule is used through SPI Interface over PCIe connector
SWCLK, SWDIO, and MCU_NRESET are connected to mini-PCIe
VCC_MAIN comes from 5V or 3.3V

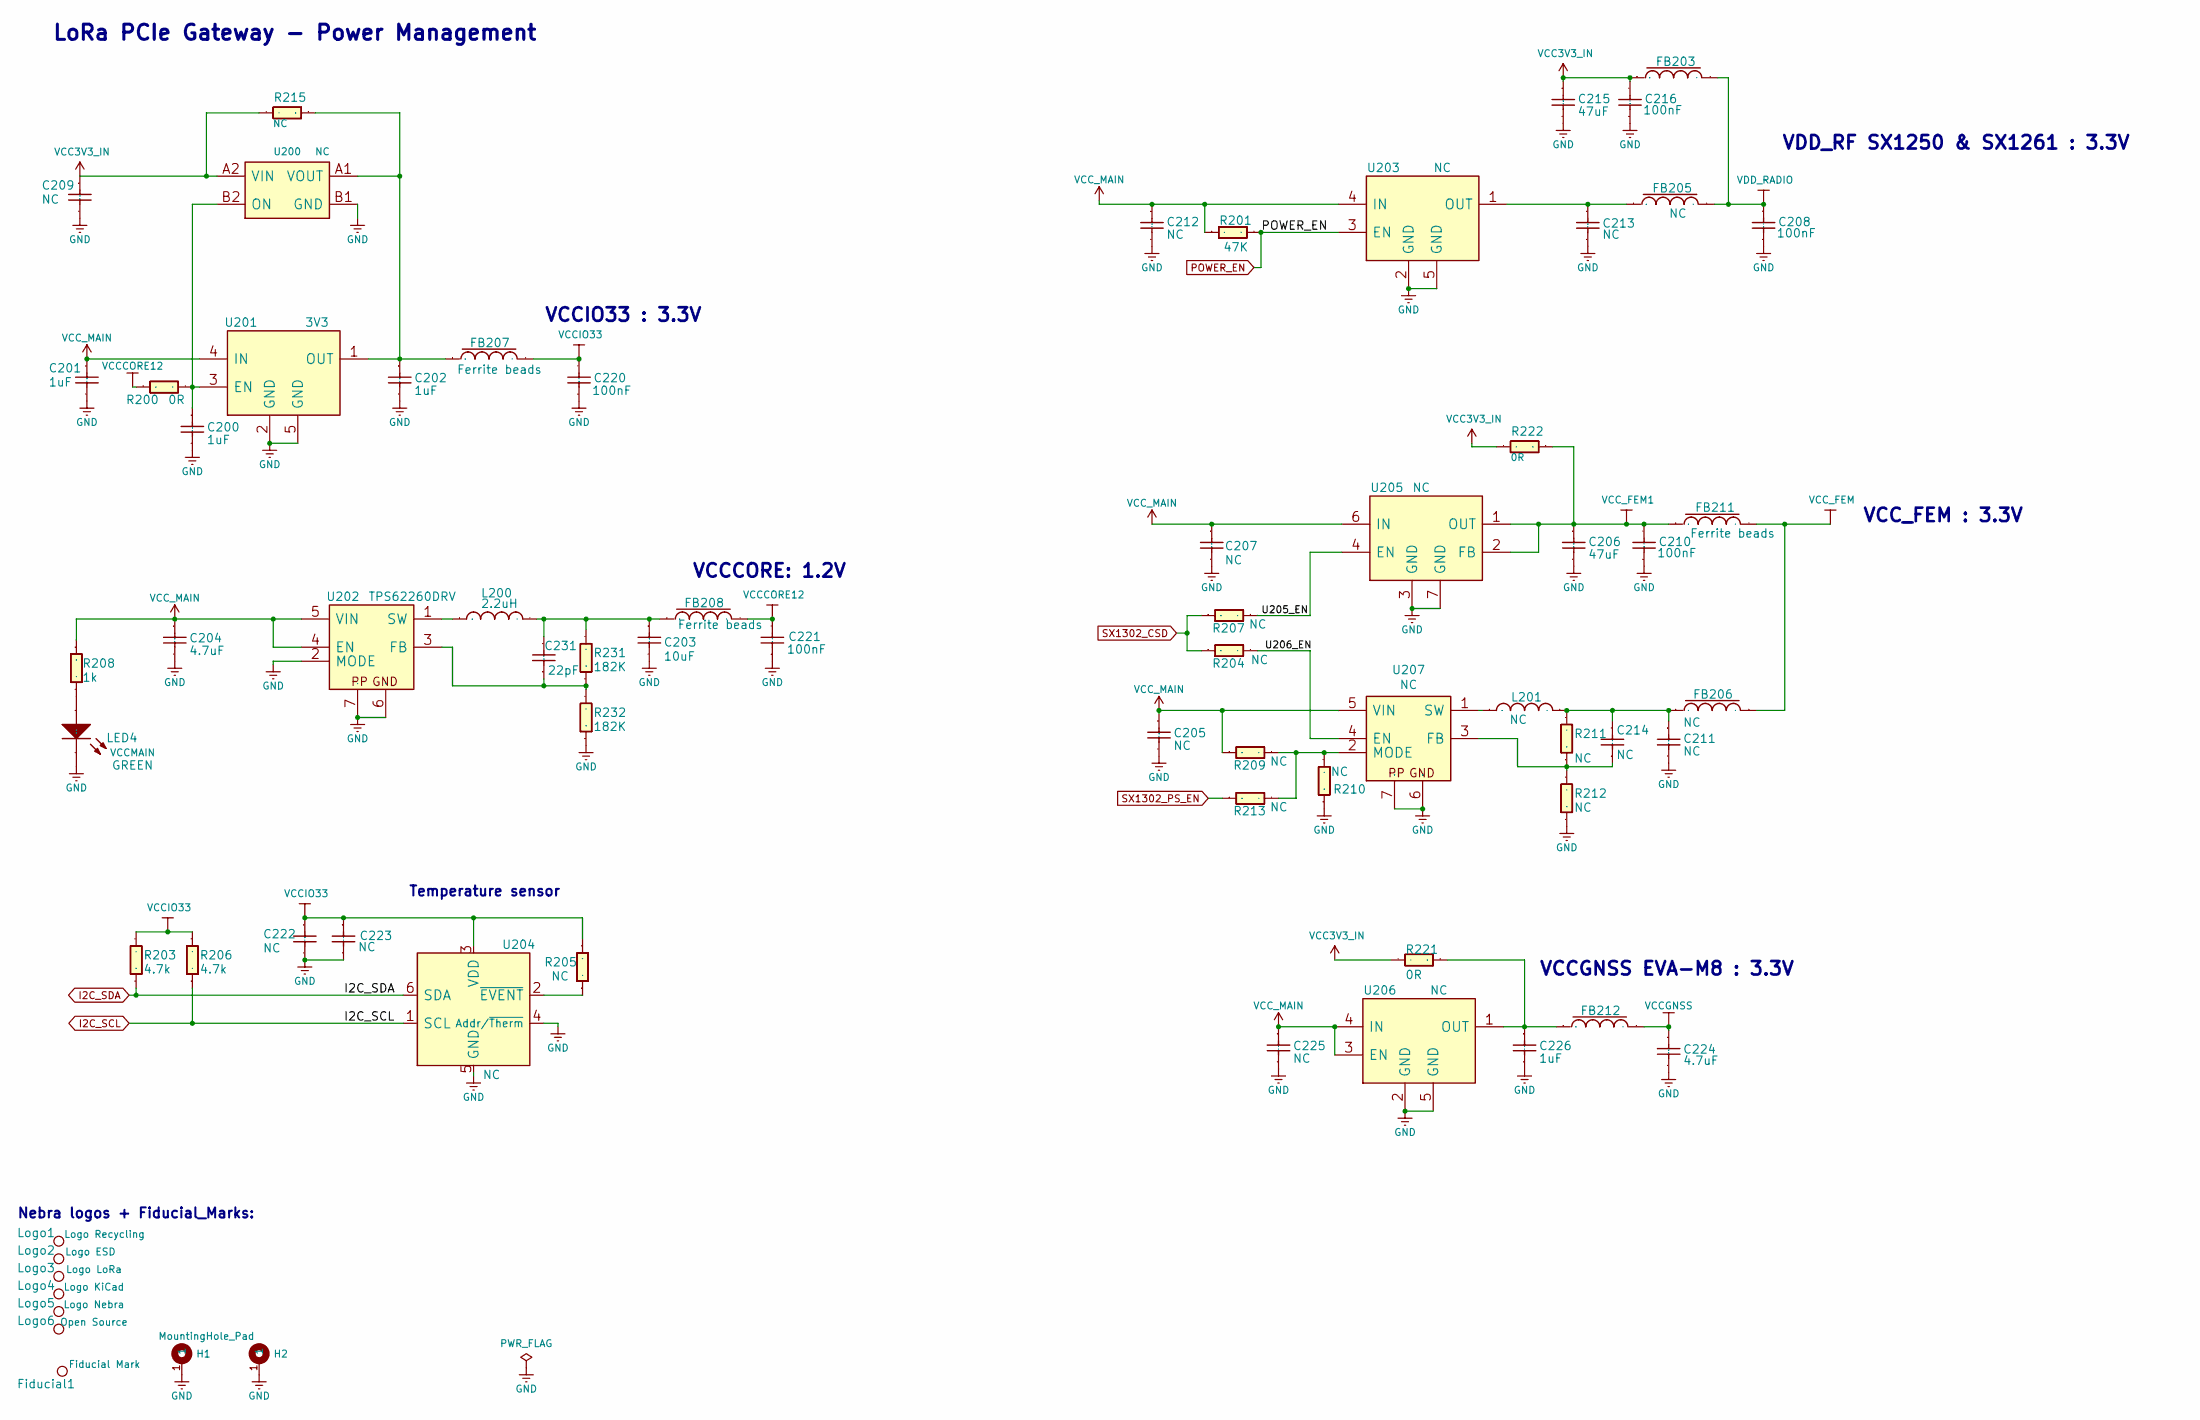
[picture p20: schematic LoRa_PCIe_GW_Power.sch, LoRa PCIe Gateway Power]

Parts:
C200, C201, C202, C226: 1uF; ccer_402_smd_small; Part Number GRM153R61A105ME95D
C203: 10uF; ccer_603_smd_small; Part Number GRM188R61C106KAAL
C204: 4.7uF; ccer_603_smd_small; Part Number GRM188R61C475KAAJD
C205: NC; ccer_603_smd_small; Part Number GRM188R61C475KAAJD
C206, C215: 47uF; ccer_603_smd_small; Part Number GRM188R60J476ME15D
C207, C211, C212: NC; ccer_603_smd_small; Part Number GRM188R61C106KAAL
C208, C210, C216, C220, C221: 100nF; ccer_402_smd_small; Part Number GMD155R71C104KA11
C209, C225: NC; ccer_402_smd_small; Part Number GRM153R61A105ME95D
C213: NC; ccer_402_smd_small; Part Number GRM155R60J475ME47D
C214: NC; ccer_201_smd_small; Part Number GRM0335C1H220FA01D
C222: NC; ccer_603_smd_small; Part Number GRM188R71A225KE15D
C223: NC; ccer_201_smd_small; Part Number GRM033C71C104KE14D
C224: 4.7uF; ccer_402_smd_small; Part Number GRM155R60J475ME47D
C231: 22pF; ccer_201_smd_small; Part Number GRM0335C1H220FA01D
FB203, FB207, FB208, FB211, FB212: Ferrite beads; rlc_402_smd_small; Part Number BLM15PG100SN1D
FB205, FB206: NC; rlc_402_smd_small; Part Number BLM15PG100SN1D
Fiducial1: NC; fiducial_mark_signal_top
H1, H2: NC; MountingHole
L200: 2.2uH; LQM2HPN2R2MJ0L; Part Number LQM2HPN2R2MJ0L
L201: NC; LQM2HPN2R2MJ0L; Part Number LQM2HPN2R2MJ0L
LED4: GREEN; CD1005-0402; Part Number APHHS1005LCGCK
Logo1: NC; Logo_Recycling
Logo2: NC; Logo_ESD
Logo3: NC; Logo_LoRa
Logo4: NC; Logo_KiCad
Logo5: NC; nebra
Logo6: NC; open_source
R200: 0R; rlc_201_smd_small; Part Number CRCW02010000Z0ED
R201: 47K; rlc_201_smd_small; Part Number CRCW020147K0
R203, R206: 4.7k; rlc_201_smd_small; Part Number CRCW02014K70FNED
R204, R207, R209, R210, R213: NC; rlc_201_smd_small; Part Number CRCW02010000Z0ED
R205: NC; rlc_201_smd_small; Part Number CRCW020147K0
R208: 1k; rlc_201_smd_small; Part Number CRCW02011K00JNED
R211: NC; rlc_201_smd_small; Part Number CRCW0201806KFNED
R212: NC; rlc_201_smd_small; Part Number CRCW0201187KFNED
R215: NC; rlc_402_smd_small; Part Number CRCW04020000ZSTD
R221, R222: 0R; rlc_402_smd_small; Part Number CRCW04020000ZSTD
R231, R232: 182K; rlc_201_smd_small; Part Number CRCW0201182KFKED
U200: NC; DSBGA-4; Part Number TPS22908
U201: 3V3; UDFN4_1x1mm; Part Number NCP114AMX330TCG
U202: TPS62260DRV; DRV0006A_V; Part Number TPS62260DRV
U203, U206: NC; UDFN4_1x1mm; Part Number NCP114AMX330TBG
U204: NC; UDFN-6L_2X2mm; Part Number STTS751-0DP3F
U205: NC; XDFN6_1.2X1.2mm; Part Number NCP176AMX330TCG
U207: NC; DRV0006A_V; Part Number TPS62260DRVR

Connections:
/SCH3/U205_EN: R207.2, U205.4 (EN)
/SCH3/U206_EN: R204.2, U207.4 (EN)
GND: C200.2, C201.2, C202.2, C203.2, C204.2, C205.2, C206.2, C207.2, C208.1, C209.2, C210.1, C211.2, C212.2, C213.2, C215.2, C216.1, C220.1, C221.1, C222.2, C223.2, C224.2, C225.2, C226.2, H1.1, H2.1, LED4.2 (K), R210.1, R212.1, R232.1, U200.B1 (GND), U201.2 (GND), U201.5 (GND), U202.2 (MODE), U202.6 (GND), U202.7 (PP), U203.2 (GND), U203.5 (GND), U204.4 (Addr/~Therm), U204.5 (GND), U205.3 (GND), U205.7 (GND), U206.2 (GND), U206.5 (GND), U207.6 (GND), U207.7 (PP); also elsewhere on the board
I2C_SCL: R206.1, U204.1 (SCL); also elsewhere on the board
I2C_SDA: R203.1, U204.6 (SDA); also elsewhere on the board
unnamed: C200.1, R200.2, U200.B2 (ON), U201.3 (EN)
unnamed: C202.1, FB207.1, R215.1, U200.A1 (VOUT), U201.1 (OUT)
unnamed: C203.1, C231.2, FB208.1, L200.2, R231.2
unnamed: C211.1, C214.2, FB206.1, L201.2, R211.2
unnamed: C213.1, FB205.1, U203.1 (OUT)
unnamed: C214.1, R211.1, R212.2, U207.3 (FB)
unnamed: C226.1, FB212.1, R221.1, U206.1 (OUT)
unnamed: C231.1, R231.1, R232.2, U202.3 (FB)
unnamed: L200.1, U202.1 (SW)
unnamed: L201.1, U207.1 (SW)
unnamed: LED4.1 (A), R208.2
unnamed: R205.1, U204.2 (~EVENT)
unnamed: R209.2, R210.2, R213.2, U207.2 (MODE)
POWER_EN: R201.2, U203.3 (EN); also elsewhere on the board
SX1302_CSD: R204.1, R207.1; also elsewhere on the board
SX1302_PS_EN: R213.1; also elsewhere on the board
VCC3V3_IN: C209.1, C215.1, C216.2, FB203.1, R215.2, R221.2, R222.2, U200.A2 (VIN); also elsewhere on the board
VCCCORE12: C221.2, FB208.2, R200.1; also elsewhere on the board
VCCGNSS: C224.1, FB212.2; also elsewhere on the board
VCCIO33: C220.2, C222.1, C223.1, FB207.2, R203.2, R205.2, R206.2, U204.3 (VDD); also elsewhere on the board
VCC_FEM: FB206.2, FB211.2; also elsewhere on the board
VCC_FEM1: C206.1, C210.2, FB211.1, R222.1, U205.1 (OUT), U205.2 (FB)
VCC_MAIN: C201.1, C204.1, C205.1, C207.1, C212.1, C225.1, R201.1, R208.1, R209.1, U201.4 (IN), U202.4 (EN), U202.5 (VIN), U203.4 (IN), U205.6 (IN), U206.3 (EN), U206.4 (IN), U207.5 (VIN); also elsewhere on the board
VDD_RADIO: C208.2, FB203.2, FB205.2; also elsewhere on the board

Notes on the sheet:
LoRa PCIe Gateway - Power Management
VCCIO33 : 3.3V
VCCCORE: 1.2V
Nebra logos + Fiducial_Marks:
Temperature sensor
VCCGNSS EVA-M8 : 3.3V
VDD_RF SX1250 & SX1261 : 3.3V
VCC_FEM : 3.3V

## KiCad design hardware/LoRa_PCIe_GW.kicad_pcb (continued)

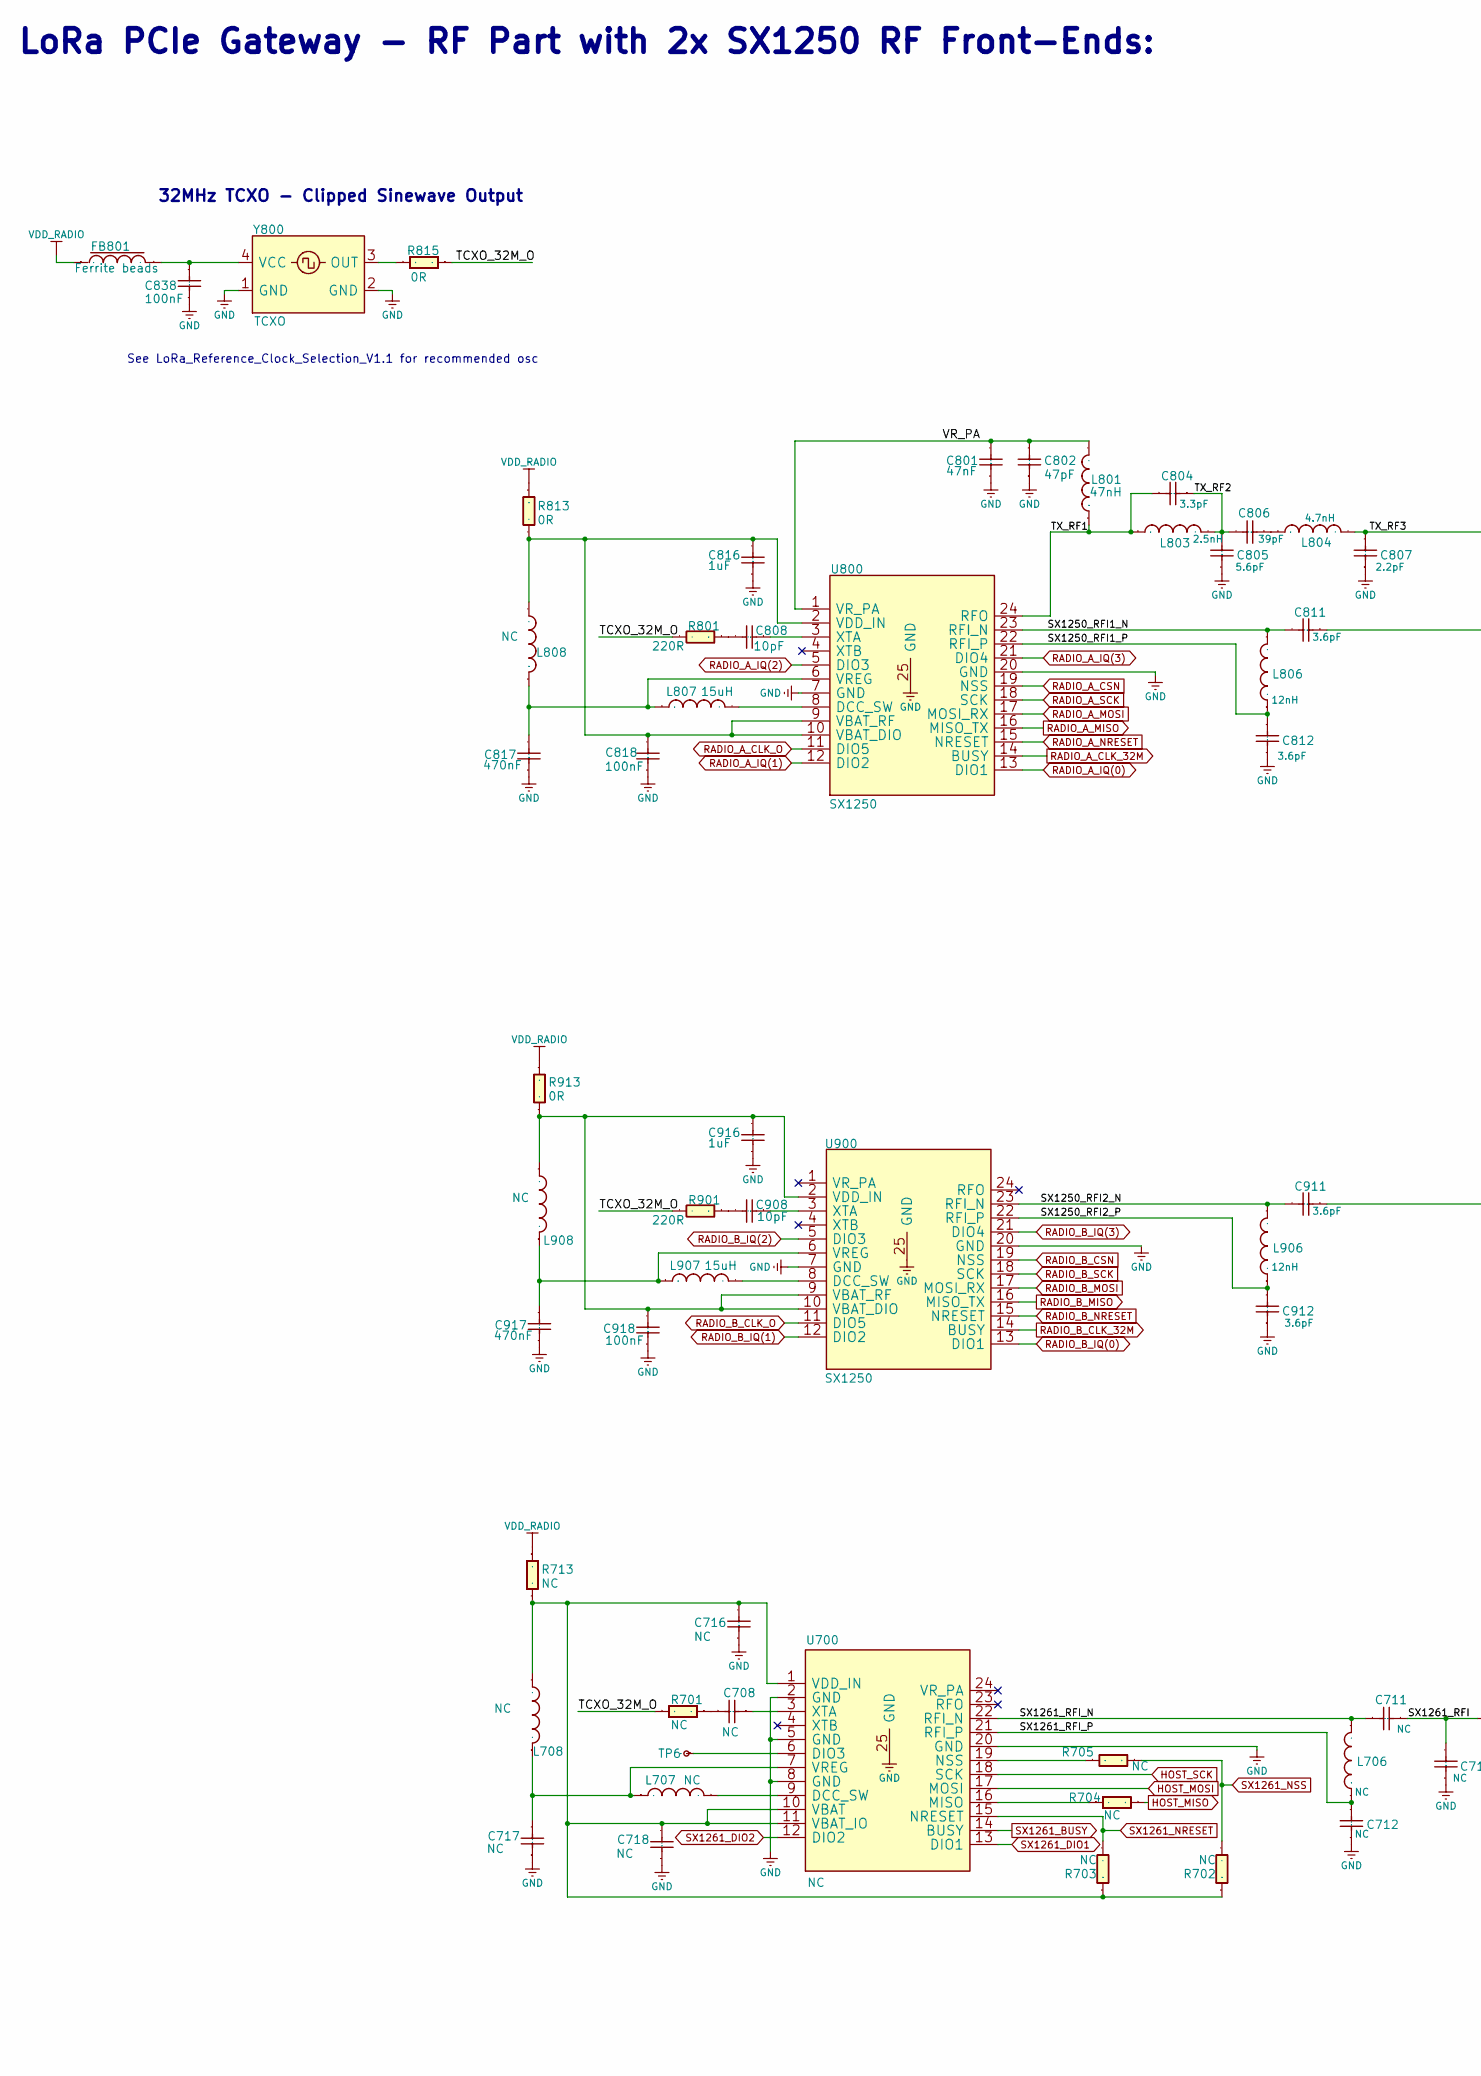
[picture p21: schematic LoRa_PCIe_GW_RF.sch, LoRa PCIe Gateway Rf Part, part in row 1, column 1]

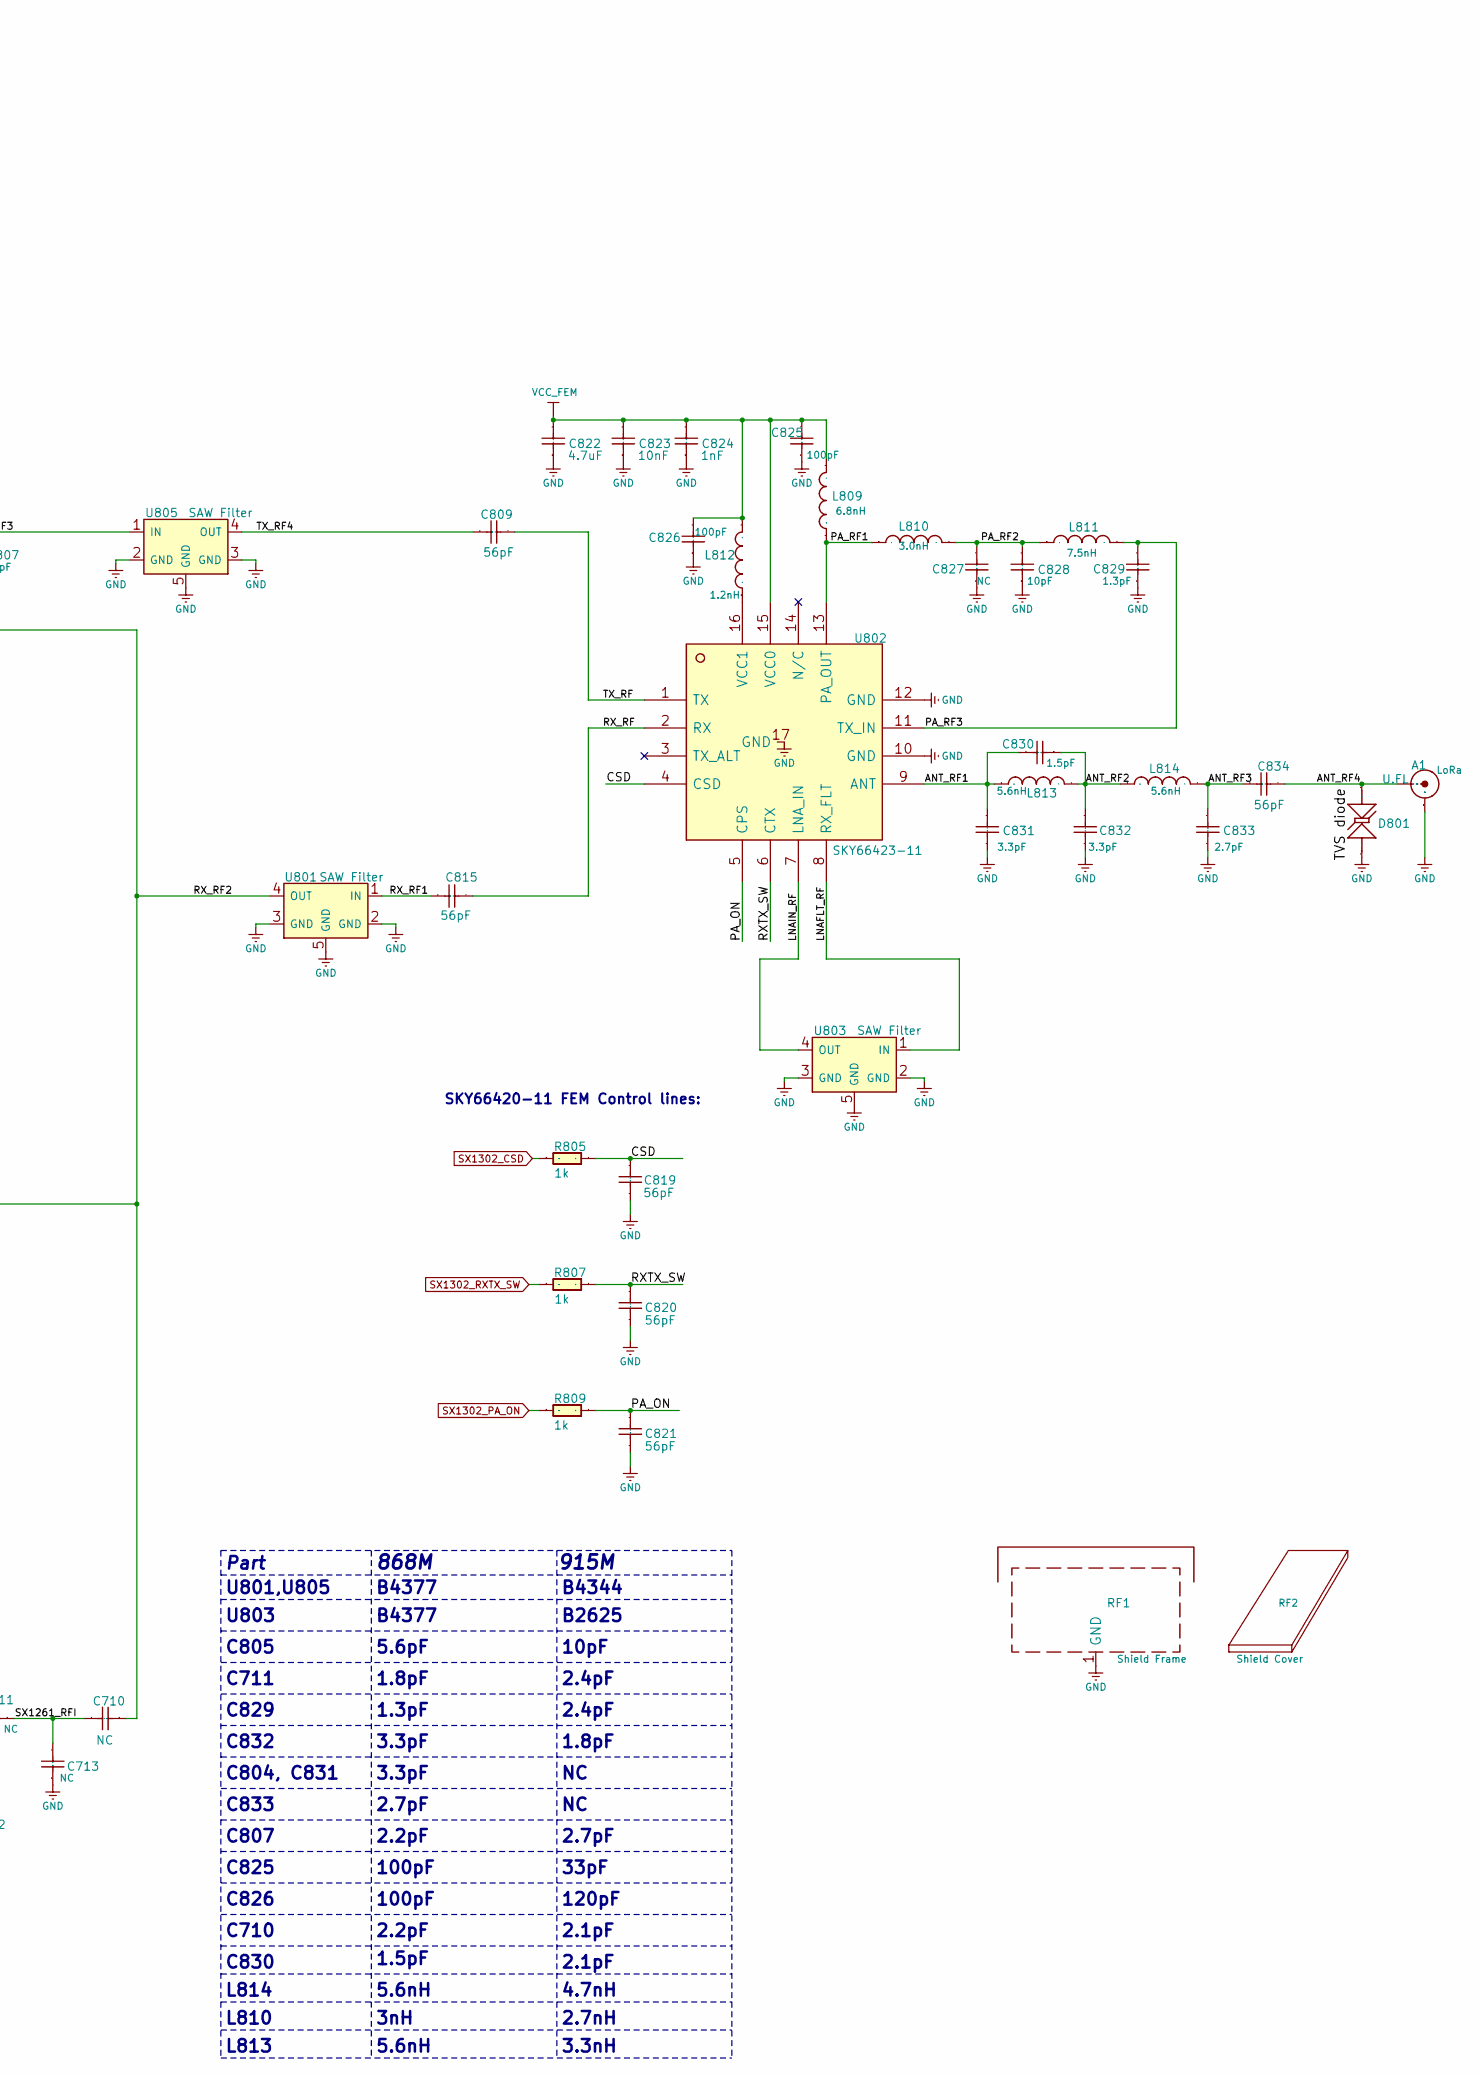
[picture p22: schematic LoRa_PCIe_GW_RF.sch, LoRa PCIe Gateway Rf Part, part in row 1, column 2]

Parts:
A1: U.FL; U.FL-R-SMT_Hirose; Part Number U.FL-R-SMT-1(80)
C708: NC; ccer_201_smd_small; Part Number GRM0335C1H100FA01
C710, C713, C827: NC; ccer_201_smd_small
C711, C712: NC; ccer_201_smd_small; Part Number GJM0335C1H1R8WB01
C716: NC; ccer_402_smd_small; Part Number GRM155R61A103KA01D
C717: NC; ccer_402_smd_small; Part Number GRM155R61A474KE15D
C718: NC; ccer_402_smd_small; Part Number GMD155R71C104KA11
C801: 47nF; ccer_402_smd_small; Part Number GRM155R71C473KA01J
C802: 47pF; ccer_201_smd_small; Part Number GRM0335C1H470JA01D
C804, C831, C832: 3.3pF; ccer_201_smd_small; Part Number GJM0335C1H3R3WB01D
C805: 5.6pF; ccer_201_smd_small; Part Number GRM0335C1H5R6WA01D
C806: 39pF; ccer_201_smd_small; Part Number GRM0335C1H390FA01D
C807: 2.2pF; ccer_201_smd_small; Part Number GJM0335C1H2R2WB01D
C808, C828, C908: 10pF; ccer_201_smd_small; Part Number GRM0335C1H100FA01
C809, C815, C819, C820, C821, C834: 56pF; ccer_201_smd_small; Part Number GRM0335C1H560FA01D
C811, C812, C911, C912: 3.6pF; ccer_201_smd_small; Part Number GJM0335C1E3R6WB01J
C816, C916: 1uF; ccer_402_smd_small; Part Number GRM153R61A105ME95D
C817, C917: 470nF; ccer_402_smd_small; Part Number GRM155R61A474KE15D
C818, C918: 100nF; ccer_402_smd_small; Part Number GMD155R71C104KA11
C822: 4.7uF; ccer_603_smd_small; Part Number GRM188R61C475KAAJD
C823: 10nF; ccer_402_smd_small; Part Number GRM155R61A103KA01D
C824: 1nF; ccer_402_smd_small; Part Number GRM155R71C102KA01D
C825, C826: 100pF; ccer_402_smd_small; Part Number GRM1555C1H101FA01D
C829: 1.3pF; ccer_201_smd_small; Part Number GJM0335C1H1R3WB01
C830: 1.5pF; ccer_201_smd_small; Part Number GJM0335C1H1R5WB01
C833: 2.7pF; ccer_201_smd_small; Part Number GJM0335C1H2R7BB01D
C838: 100nF; ccer_201_smd_small; Part Number GRM033C71C104KE14D
D801: SLP1006P2T; Part Number LXES15AAA1-153
FB801: Ferrite beads; rlc_402_smd_small; Part Number BLM15PG100SN1D
L706: NC; rlc_402_smd_small; Part Number LQW15AN15NH00D
L707: NC; rlc_805_smd_small; Part Number MLZ2012M150WTD25
L708: NC; rlc_402_smd_small; Part Number LQW15AN47NJ00D
L801: 47nH; rlc_402_smd_small; Part Number LQW15AN47NJ00D
L803: 2.5nH; rlc_402_smd_small; Part Number LQW15AN2N5C00D
L804: 4.7nH; rlc_402_smd_small; Part Number LQW15AN4N7C00D
L806, L906: 12nH; rlc_402_smd_small; Part Number LQW15AN12NH00D
L807, L907: 15uH; rlc_805_smd_small; Part Number MLZ2012M150WTD25
L808, L908: NC; rlc_402_smd_small
L809: 6.8nH; rlc_402_smd_small; Part Number LQW15AN6N8G80D
L810: 3.0nH; rlc_402_smd_small; Part Number LQW15AN3N0C80D
L811: 7.5nH; rlc_402_smd_small; Part Number LQW15AN7N5J00D
L812: 1.2nH; rlc_402_smd_small; Part Number LQP15MN1N2B02
L813, L814: 5.6nH; rlc_402_smd_small; Part Number LQW15AN5N6D10D
R701: NC; rlc_201_smd_small; Part Number CRCW0201220RJNED
R702, R703: NC; rlc_201_smd_small; Part Number CRCW020110K0
R704: NC; rlc_201_smd_small; Part Number CRCW0201100R
R705: NC; rlc_201_smd_small; Part Number CRCW02010000Z0ED
R713: NC; rlc_201_smd_small
R801, R901: 220R; rlc_201_smd_small; Part Number CRCW0201220RJNED
R805, R807, R809: 1k; rlc_201_smd_small; Part Number CRCW02011K00JNED
R813, R913: 0R; rlc_402_smd_small; Part Number CRCW04020000ZSTD
R815: 0R; rlc_201_smd_small; Part Number CRCW02010000Z0ED
RF1: Shield Frame; SMS-458F_Shield; Part Number SMS-458F
RF2: Shield Cover; SMS-458C_Shield_cover; Part Number SMS-458C
TP6: NC; PIN_SMD
U700: NC; vqfn24_4x4mm; Part Number SX1261IMLTRT
U800, U900: SX1250; vqfn24_4x4mm; Part Number SX1250IMLTRT
U801, U803, U805: SAW Filter; QCS5P_1.4x1.1mm; Part Number B39871B4377P810
U802: SKY66423-11; SKY66420_16P_3x3mm; Part Number SKY66423-11
Y800: TCXO; TCXO_2x1_6mm; Part Number NT2016SA 32MHz END4263A

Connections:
/SCH1/ANT_RF1: C830.2, C831.2, L813.1, U802.9 (ANT)
/SCH1/ANT_RF2: C830.1, C832.1, L813.2, L814.1
/SCH1/ANT_RF3: C833.1, C834.1, L814.2
/SCH1/ANT_RF4: A1.1 (Signal), C834.2, D801.1 (A)
/SCH1/CSD: C819.2, R805.2, U802.4 (CSD)
/SCH1/LNAFLT_RF: U802.8 (RX_FLT), U803.1 (IN)
/SCH1/LNAIN_RF: U802.7 (LNA_IN), U803.4 (OUT)
/SCH1/PA_ON: C821.2, R809.2, U802.5 (CPS)
/SCH1/PA_RF1: L809.1, L810.1, U802.13 (PA_OUT)
/SCH1/PA_RF2: C827.2, C828.2, L810.2, L811.1
/SCH1/PA_RF3: C829.2, L811.2, U802.11 (TX_IN)
/SCH1/RXTX_SW: C820.2, R807.2, U802.6 (CTX)
/SCH1/RX_RF: C815.2, U802.2 (RX)
/SCH1/RX_RF1: C815.1, U801.1 (IN)
/SCH1/RX_RF2: C710.1, C811.1, C911.1, U801.4 (OUT)
/SCH1/SX1250_RFI1_N: C811.2, L806.2, U800.23 (RFI_N)
/SCH1/SX1250_RFI1_P: C812.2, L806.1, U800.22 (RFI_P)
/SCH1/SX1250_RFI2_N: C911.2, L906.2, U900.23 (RFI_N)
/SCH1/SX1250_RFI2_P: C912.2, L906.1, U900.22 (RFI_P)
/SCH1/SX1261_RFI: C710.2, C711.1, C713.2
/SCH1/SX1261_RFI_N: C711.2, L706.2, U700.22 (RFI_N)
/SCH1/SX1261_RFI_P: C712.2, L706.1, U700.21 (RFI_P)
/SCH1/TCXO_32M_O: R701.2, R801.2, R815.1, R901.2
/SCH1/TX_RF: C809.2, U802.1 (TX)
/SCH1/TX_RF1: C804.2, L801.1, L803.1, U800.24 (RFO)
/SCH1/TX_RF2: C804.1, C805.2, C806.2, L803.2
/SCH1/TX_RF3: C807.2, L804.2, U805.1 (IN)
/SCH1/TX_RF4: C809.1, U805.4 (OUT)
/SCH1/VR_PA: C801.2, C802.2, L801.2, U800.1 (VR_PA)
GND: A1.2 (GND), A1.3 (GND), C712.1, C713.1, C716.1, C717.1, C718.1, C801.1, C802.1, C805.1, C807.1, C812.1, C816.1, C817.1, C818.1, C819.1, C820.1, C821.1, C822.1, C823.1, C824.1, C825.1, C826.1, C827.1, C828.1, C829.1, C831.1, C832.2, C833.2, C838.1, C912.1, C916.1, C917.1, C918.1, D801.2 (K), RF1.1, U700.2 (GND), U700.5 (GND), U700.8 (GND), U700.20 (GND), U700.25 (GND), U800.7 (GND), U800.20 (GND), U800.25 (GND), U801.2 (GND), U801.3 (GND), U801.5 (GND), U802.10 (GND), U802.12 (GND), U802.17 (GND), U803.2 (GND), U803.3 (GND), U803.5 (GND), U805.2 (GND), U805.3 (GND), U805.5 (GND), U900.7 (GND), U900.20 (GND), U900.25 (GND), Y800.1 (GND), Y800.2 (GND); also elsewhere on the board
HOST_MISO: R704.2; also elsewhere on the board
HOST_MOSI: U700.17 (MOSI); also elsewhere on the board
HOST_SCK: U700.18 (SCK); also elsewhere on the board
unnamed: C708.1, U700.3 (XTA)
unnamed: C708.2, R701.1
unnamed: C716.2, C718.2, L708.2, R702.1, R703.1, R713.2, U700.1 (VDD_IN), U700.10 (VBAT), U700.11 (VBAT_IO)
unnamed: C717.2, L707.1, L708.1, U700.7 (VREG)
unnamed: C806.1, L804.1
unnamed: C808.1, U800.3 (XTA)
unnamed: C808.2, R801.1
unnamed: C816.2, C818.2, L808.2, R813.2, U800.2 (VDD_IN), U800.9 (VBAT_RF), U800.10 (VBAT_DIO)
unnamed: C817.2, L807.1, L808.1, U800.6 (VREG)
unnamed: C838.2, FB801.2, Y800.4 (VCC)
unnamed: C908.1, U900.3 (XTA)
unnamed: C908.2, R901.1
unnamed: C916.2, C918.2, L908.2, R913.2, U900.2 (VDD_IN), U900.9 (VBAT_RF), U900.10 (VBAT_DIO)
unnamed: C917.2, L907.1, L908.1, U900.6 (VREG)
unnamed: L707.2, U700.9 (DCC_SW)
unnamed: L807.2, U800.8 (DCC_SW)
unnamed: L812.1, U802.16 (VCC1)
unnamed: L907.2, U900.8 (DCC_SW)
unnamed: R704.1, U700.16 (MISO)
unnamed: R705.1, U700.19 (NSS)
unnamed: R815.2, Y800.3 (OUT)
unnamed: TP6.1, U700.6 (DIO3)
RADIO_A_CLK_32M: U800.14 (BUSY); also elsewhere on the board
RADIO_A_CLK_O: U800.11 (DIO5); also elsewhere on the board
RADIO_A_CSN: U800.19 (NSS); also elsewhere on the board
RADIO_A_IQ(0): U800.13 (DIO1); also elsewhere on the board
RADIO_A_IQ(1): U800.12 (DIO2); also elsewhere on the board
RADIO_A_IQ(2): U800.5 (DIO3); also elsewhere on the board
RADIO_A_IQ(3): U800.21 (DIO4); also elsewhere on the board
RADIO_A_MISO: U800.16 (MISO_TX); also elsewhere on the board
RADIO_A_MOSI: U800.17 (MOSI_RX); also elsewhere on the board
RADIO_A_NRESET: U800.15 (NRESET); also elsewhere on the board
RADIO_A_SCK: U800.18 (SCK); also elsewhere on the board
RADIO_B_CLK_32M: U900.14 (BUSY); also elsewhere on the board
RADIO_B_CLK_O: U900.11 (DIO5); also elsewhere on the board
RADIO_B_CSN: U900.19 (NSS); also elsewhere on the board
RADIO_B_IQ(0): U900.13 (DIO1); also elsewhere on the board
RADIO_B_IQ(1): U900.12 (DIO2); also elsewhere on the board
RADIO_B_IQ(2): U900.5 (DIO3); also elsewhere on the board
RADIO_B_IQ(3): U900.21 (DIO4); also elsewhere on the board
RADIO_B_MISO: U900.16 (MISO_TX); also elsewhere on the board
RADIO_B_MOSI: U900.17 (MOSI_RX); also elsewhere on the board
RADIO_B_NRESET: U900.15 (NRESET); also elsewhere on the board
RADIO_B_SCK: U900.18 (SCK); also elsewhere on the board
SX1261_BUSY: U700.14 (BUSY); also elsewhere on the board
SX1261_DIO1: U700.13 (DIO1); also elsewhere on the board
SX1261_DIO2: U700.12 (DIO2); also elsewhere on the board
SX1261_NRESET: R703.2, U700.15 (NRESET); also elsewhere on the board
SX1261_NSS: R702.2, R705.2; also elsewhere on the board
SX1302_CSD: R805.1; also elsewhere on the board
SX1302_PA_ON: R809.1; also elsewhere on the board
SX1302_RXTX_SW: R807.1; also elsewhere on the board
VCC_FEM: C822.2, C823.2, C824.2, C825.2, C826.2, L809.2, L812.2, U802.15 (VCC0); also elsewhere on the board
VDD_RADIO: FB801.1, R713.1, R813.1, R913.1; also elsewhere on the board

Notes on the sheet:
LoRa PCIe Gateway - RF Part with 2x SX1250 RF Front-Ends:
SKY66420-11 FEM Control lines:
32MHz TCXO - Clipped Sinewave Output
See LoRa_Reference_Clock_Selection_V1.1 for recommended osc
Part
868M
915M
U801,U805
B4377
B4344
U803
B2625
C805
5.6pF
10pF
C711
1.8pF
2.4pF
C829
1.3pF
C832
3.3pF
C804, C831
C833
2.7pF
C807
2.2pF
C825
100pF
33pF
C826
120pF
C710
2.1pF
C830
1.5pF
L814
5.6nH
4.7nH
L810

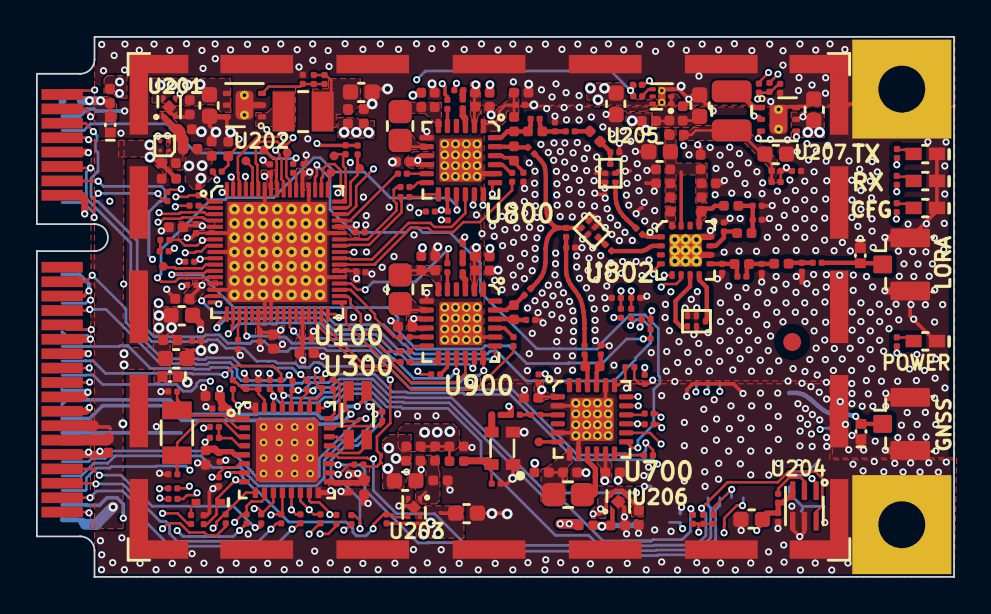
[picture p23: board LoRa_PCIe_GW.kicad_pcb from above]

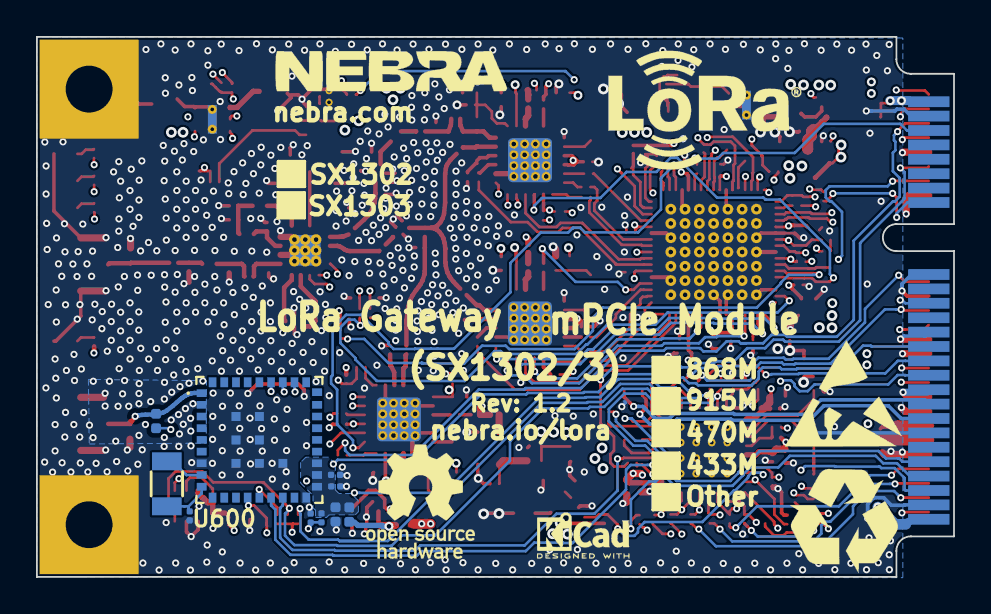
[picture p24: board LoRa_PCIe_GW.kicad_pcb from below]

Board: 6 copper layers, 50.9 x 30.0 mm, 269 parts (16 on the bottom side), 190 nets.

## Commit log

2021-03-11 Initial Design Rev:1.0
    [LoRa_PCIe_GW-SPI_868M_GNSS-BOM.csv, LoRa_PCIe_GW.kicad_pcb, LoRa_PCIe_GW.sch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]
2021-04-13 Updates according to Corecell_V3 Reference design.
    [LoRa_PCIe_GW-SPI_868M_GNSS-BOM.csv, LoRa_PCIe_GW-SPI_868M_GNSS-BOM.xlsx, LoRa_PCIe_GW.kicad_pcb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]
2021-07-29 Added BOM and position files for US915MHz variant
    [LoRa_PCIe_GW-SPI_US915M_GNSS-BOM.csv]
2021-07-29 Corrected quantity field for U801, U805
    [LoRa_PCIe_GW-SPI_US915M_GNSS-BOM.csv]
2021-07-31 Added BOM for non GNSS variants. Few part numbers corrected in design.
    [LoRa_PCIe_GW-SPI_868M_NON-GNSS_BOM.csv, LoRa_PCIe_GW-SPI_US915M_NON-GNSS_BOM.csv, LoRa_PCIe_GW_GPS.sch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]
2022-01-22 fix: fix bom quantities on SAW filters
    BOM quantities were incorrect.
    [LoRa_PCIe_GW-SPI_US915M_NON-GNSS_NON_TEMP_BOM.csv]
